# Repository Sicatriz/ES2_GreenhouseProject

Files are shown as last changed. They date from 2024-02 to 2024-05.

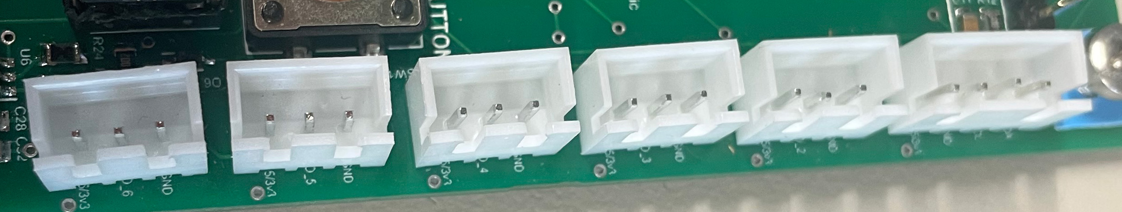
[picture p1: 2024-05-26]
doc/jstCon.jpg

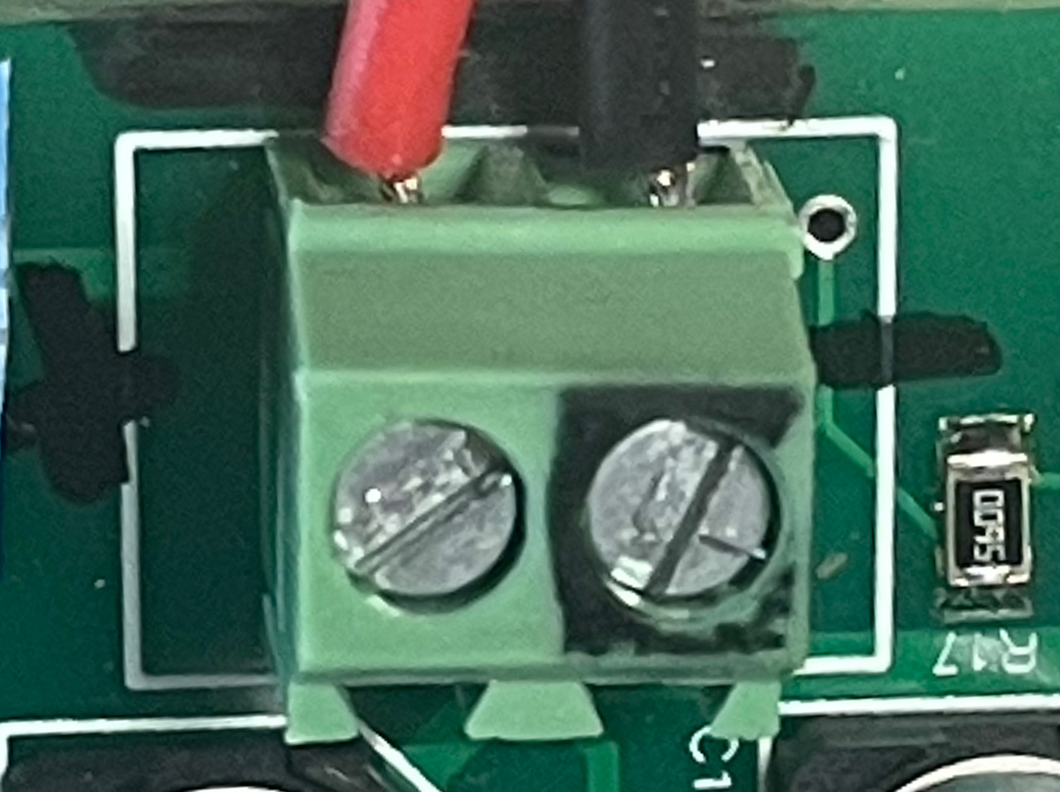
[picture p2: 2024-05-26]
doc/terminalBlock.jpg

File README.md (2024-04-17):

# **ES2 Greenhouse Project**

In dit onderzoek trachten wij een prototype te ontwerpen voor de automatisatie van een groeikas.  Op basis van de sensordata kunnen er dan acties aangestuurd worden zoals bewatering op basis van de grondvochtigheid, verluchting op basis van de temperatuur en/of schaduwvoorziening op basis van de lichtsterkte.

## **About the project**

## **Used sensors**

## **Schematic**

## **PCB design**

## **Software**

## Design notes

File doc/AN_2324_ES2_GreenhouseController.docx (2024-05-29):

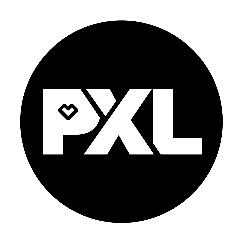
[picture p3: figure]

ELEKTRONICA-ICT

Elektronische systemen 2 2023-2024

GREENHOUSE CONTROLLER

Author | Miguel Nunez Xander Aerts

# Abstract

This paper introduces a novel approach for the development of a prototype controller tasked with sensor data acquisition tailored for greenhouse environments. The study focuses on the design, implementation, and evaluation of an integrated system facilitating real-time data collection and analysis to optimize growth conditions within greenhouses.

Content

# 1 Introduction

Greenhouse agriculture plays a crucial role in ensuring food security and sustainable food production amid an increasingly variable climate and environment. Precise monitoring and control of growth conditions within greenhouses are imperative for maximizing yield and minimizing resource consumption. In this context, this research focuses on developing a prototype controller capable of reading sensors to measure critical parameters influencing crop growth.

The proposed prototype is driven by the combination of an ATMega 328PU chip from an Arduino Uno and an ARM Cortex M4 processor from an Arduino 33 BLE. This combination of microcontrollers provides the computational power and connectivity necessary for real-time data collection and processing in a greenhouse environment.

The sensor values measured include air and soil humidity, temperature, electrical soil conductivity, and air pressure. These parameters are vital for understanding growth conditions and identifying potential stressors affecting plant growth.

The prototype design incorporates a modular architecture that offers flexibility for adjustments to various greenhouse configurations and crop types. By integrating electronics and sensor technologies, this research aims to deliver an accurate and reliable control system empowering growers to gain real-time insights and optimize their cultivation practices.

# 2 Hardware

## 2.1 PCB

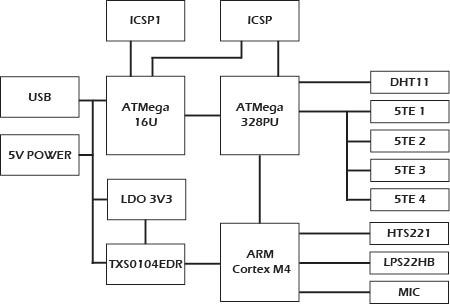
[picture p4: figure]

## 2.1.1 Block diagram and schematic

Figure 1: block diagram

The controller can be powered via micro USB or a 5V DC power jack. Programming of the chips can be done through the same micro USB port or via the ICSP1 and ICSP header.

The ATMega chip circuits are directly powered with 5V, while the ARM chip circuit is powered with 3.3V through the LDO and level shifter.

The ATMega16U serves as both a USB to serial converter and can be configured, via JP3, into different modes (Debugwire support, ISP programmer, or ISP header).

The ATMega328PU circuit processes the DHT11 and 5TE sensors, while the ARM circuit handles the built-in sensors from the Arduino 33 Sense BLE.

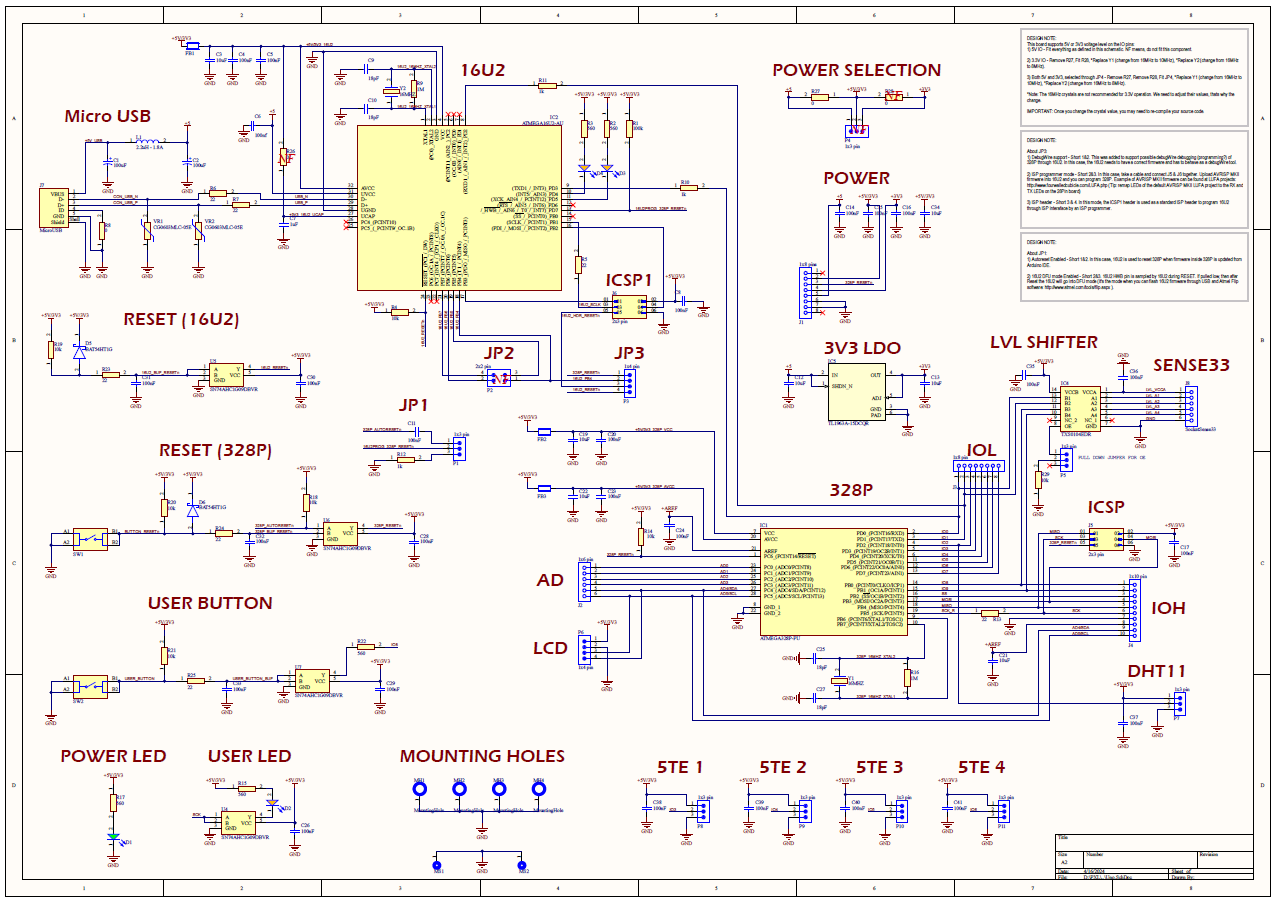
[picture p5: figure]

Figure 2: Schematic

## 2.1.2 PCB layout

The bottom plane comprises three distinct zones: ground, 5V, and 3V, as delineated in Figure 3 by respective blue, red, and green markings. This configuration facilitates easy access to the voltage channels for all components, while also partially mitigating electromagnetic interference (EMI) and electromagnetic susceptibility (EMS).

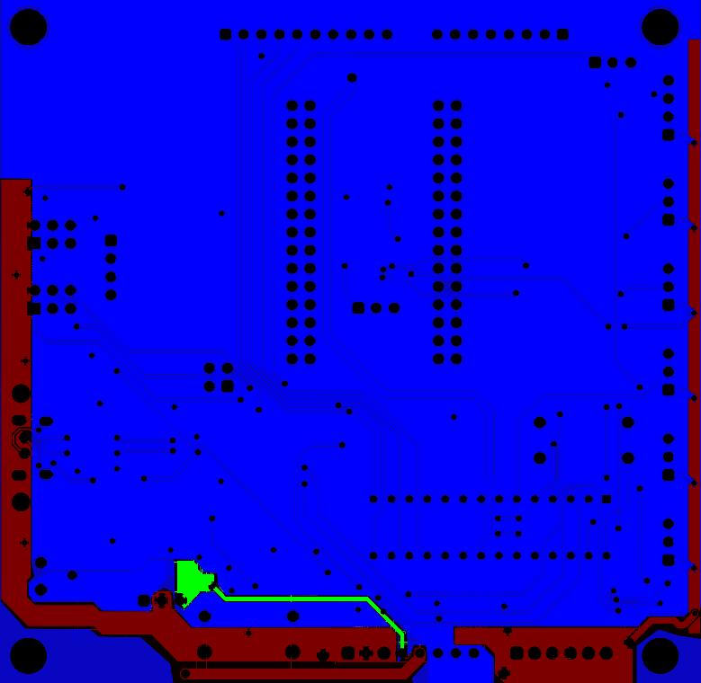
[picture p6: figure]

Figure 3: Bottom layer with ground, 5V and 3.3V polygons

The majority of signal traces are situated on the top layer. As depicted in Figure 4, the distribution is demarcated by a red colour for the Uno circuit, a green colour for the Sense BLE and level shifter circuit, and blue colour for the sensor connectors.

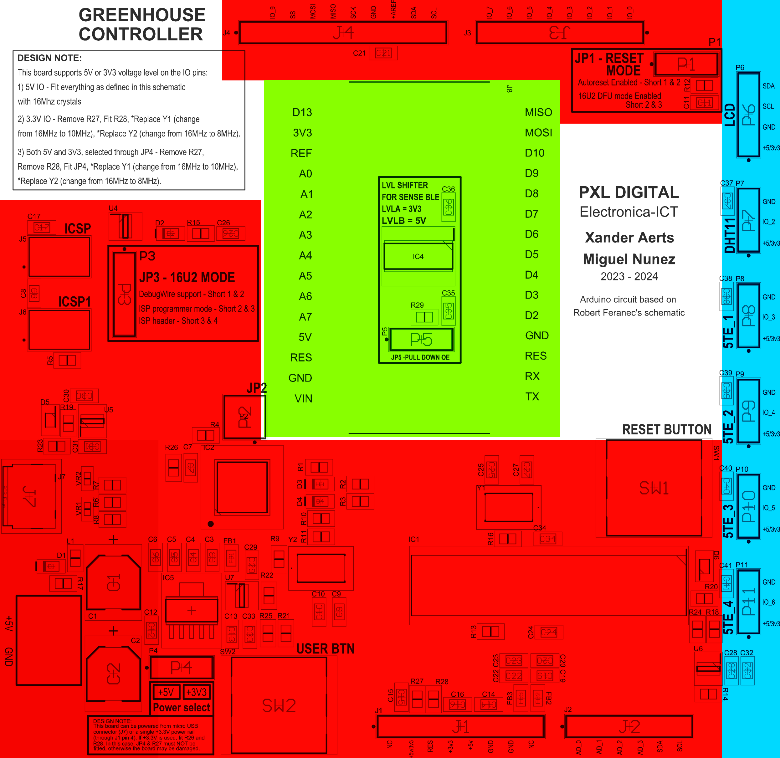
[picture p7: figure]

Figure 4: Top layer zones

## 2.1.3 Board connectors

## 2.1.3.1 Micro USB

The micro USB port serves the dual function of supplying power to the system and facilitating programming via the Arduino IDE. The USB connector was further mechanically reinforced via the addition of a metal bridge. Nevertheless, practical issues have been encountered with these connectors. Following exposure to the reflow oven, the data pins exhibited instances of short circuiting, impeding the successful uploading of sketches. After solving this short and despite recognition by the computer upon connection of the USB cable, sketch uploading functionality remains suboptimal.

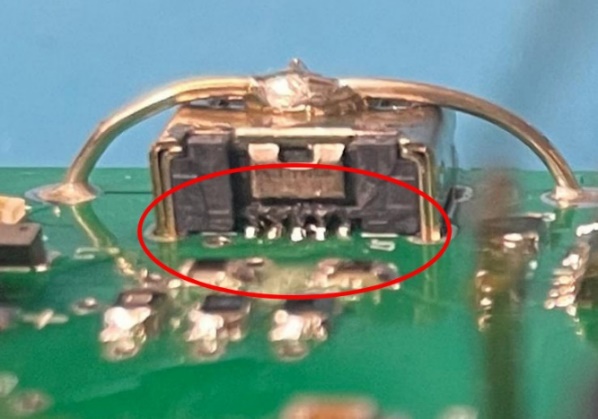
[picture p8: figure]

Figure 5: MicroUSB with shorted datapins

## 2.1.3.2 JST XH

JST type connectors are integrated on the PCB for connecting the sensor connectors and the LCD module, facilitating rapid assembly and disassembly.

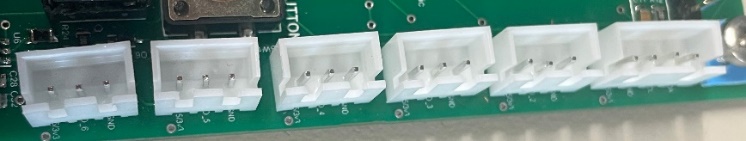
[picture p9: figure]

Figure 6: JST connectors for sensors and display

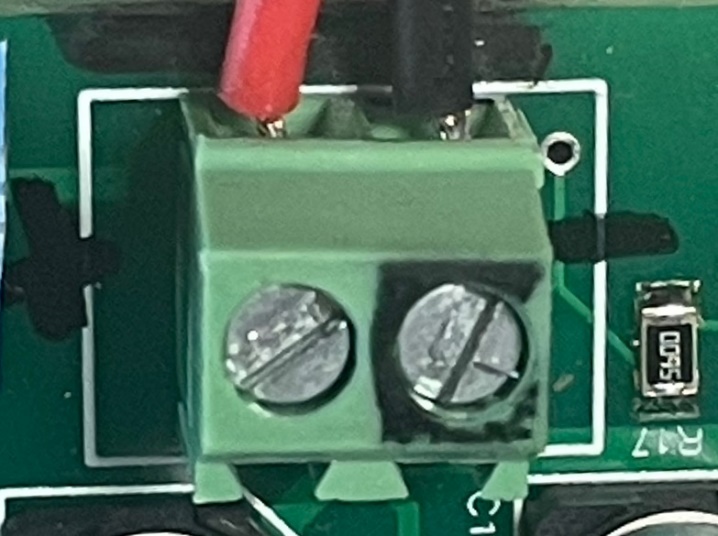
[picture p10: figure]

## 2.1.3.3 Terminal Block

Figure 7: Terminal block for power

A terminal block is incorporated to supply power to the controller independently of the USB connector. This terminal block is connected to a power jack on the enclosure, facilitating the seamless use of standard adapters.

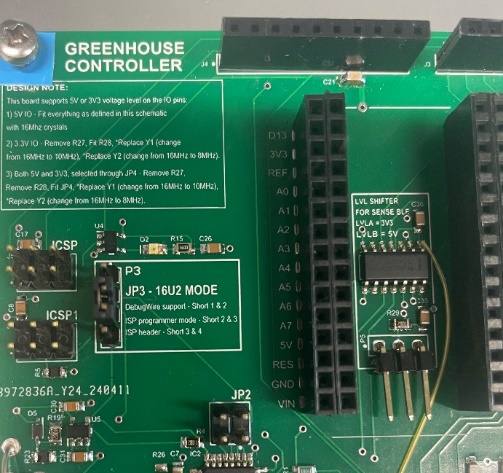
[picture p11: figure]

## 2.1.3.4 Headers

Figure 8: Pin headers and sockets

Several sockets, including J4, J3, J2, and J1, are provided to make the unused GPIOs accessible for expansions. Additionally, there are pin headers with specific functions: ICSP and ISCP1 for programming the ATMega ICs, JP3 for selecting the programming mode, JP1 for selecting the reset mode, JP2 for modifying the ATMega16u settings, P4 for power selection, and P5 for activating the pull-up of the level shifter. J8 is a custom-made footprint designed to duplicate the pins of the Arduino 33 Sense.

## 2.2 Sensoren

## 2.2.1 5TE

The 5TE 3-Prong Design sensor, developed by Decagon, is a versatile and cost-effective instrument used to measure volumetric water content (VWC), electrical conductivity (EC), and temperature in soils. Utilizing capacitance/frequency domain technology at a 70 MHz frequency, the 5TE sensor minimizes the effects of soil texture and salinity, thereby enhancing measurement accuracy across diverse soil types. The sensor's robust design includes a stainless steel electrode array for EC measurement and an onboard thermistor for temperature detection.

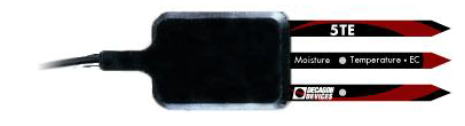
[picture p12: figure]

Figure 9: 5TE sensor

One of the key features of the 5TE sensor is its compatibility with the SDI-12 communication protocol, a widely adopted standard for interfacing environmental sensors with data loggers and acquisition systems. SDI-12 allows multiple sensors to share a common three-wire bus (power, ground, and data), facilitating efficient data collection from numerous sensors with unique addresses on a single bus. This protocol supports two-way communication, enabling the data logger to both send commands to and receive data from the sensor.

The SDI-12 implementation in the 5TE sensor supports standard commands for sensor identification, measurement initiation, and data retrieval. For instance, the INFO command (aI!) returns detailed sensor information, including the sensor's address, manufacturer, model, version, and serial number. The MEASUREMENT command (aM!) triggers the sensor to begin measurements, while the DATA command (aD0!) retrieves the measured values of VWC, EC, and temperature.

Decagon has optimized the 5TE sensor's SDI-12 circuit to support up to 62 sensors on a single bus, significantly exceeding the standard limit of 10 sensors. This enhancement is achieved through a low impedance variant of the standard SDI-12 circuit, although it necessitates careful bus management to handle potential faults and ensure reliable operation. The sensor’s digital communication capabilities, low power consumption, and robust encapsulation make it well-suited for long-term field deployments in diverse environmental conditions.

For detailed integration guidelines and to troubleshoot potential issues related to bus configuration, power supply, and grounding, users are encouraged to consult Decagon's comprehensive integrator guide. This document provides essential information for establishing reliable communication between the 5TE sensor and data acquisition systems, ensuring accurate and consistent environmental monitoring.

## 2.2.2 DHT11

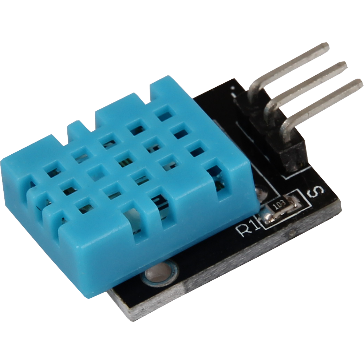
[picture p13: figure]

The SEN-KY015TF DHT11 sensor is a cost-effective and reliable device used to measure temperature and relative humidity. It operates with a temperature range of 0°C to 50°C and a humidity range of 20% to 90% RH, providing accuracies of ±2°C and ±5% RH, respectively. The sensor communicates via a single-wire digital protocol, making it easy to integrate into various systems. Common applications include environmental monitoring, home automation, agricultural management, and industrial processes where basic environmental sensing is required.

Figure 10: DHT11 sensor

Integrating the DHT11, expands its utility in complex and remote environmental monitoring setups. This integration facilitates reliable data acquisition and enhances the sensor’s applicability in diverse and demanding environments.

## 2.2.3 Sense 33 BLE

The Arduino Nano 33 BLE Sense is an excellent platform for embedded machine learning, integrating numerous sensors alongside its nRF52840 microcontroller running on Arm® Mbed™ OS. This board is equipped with a powerful 2.4 GHz Bluetooth® 5 Low Energy module, allowing for seamless wireless communication using the ArduinoBLE library.

For motion detection, the LSM9DS1 inertial measurement unit combines a 3D accelerometer, gyroscope, and magnetometer, enabling precise orientation, motion, and vibration sensing. Audio applications benefit from the MP34DT05 omnidirectional digital microphone, which captures sound for real-time analysis, supported by the PDM library. Proximity and gesture detection are facilitated by the APDS9960 sensor, which can be programmed to recognize hand gestures and control the built-in RGB LED. The LPS22HB barometric pressure sensor provides accurate pressure measurements and can calculate altitude, while the HTS221 sensor measures both temperature and humidity with high accuracy, making it ideal for environmental monitoring.

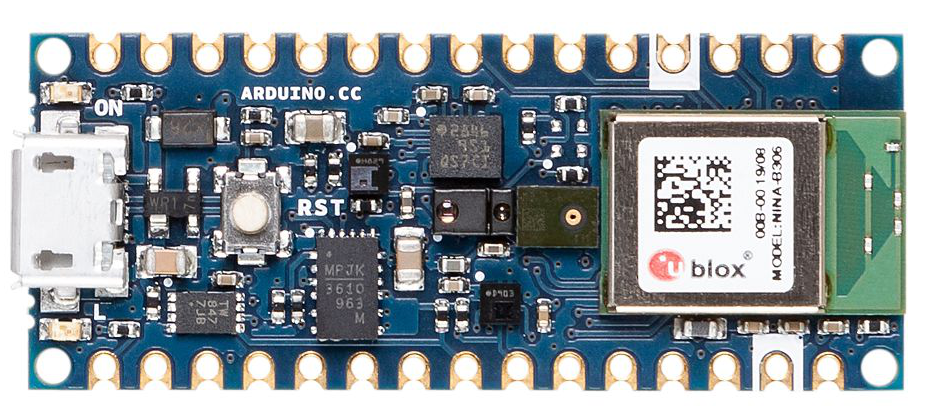
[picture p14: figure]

Figure 11: Arduino Nano 33 sense BLE

## 2.3 LCD display

For visualizing data in this project, we utilized the HD44780 16x2 LCD display, known for its simplicity and effectiveness in displaying alphanumeric characters. This module, measuring 80 mm x 36 mm x 12.5 mm, features a 16-character by 2-line resolution, making it ideal for clear and concise data presentation. It supports both 3.3V and 5V operating voltages and offers a wide operating temperature range from -10°C to +60°C, ensuring reliable performance in various environments.

The HD44780 display includes a white LED backlight and operates in both 8-bit and 4-bit parallel modes, offering flexibility in microcontroller interfacing. Key pins like RS, RW, and E facilitate easy control over data and command registers, while the VO pin allows for contrast adjustment. The module's robust design and straightforward connection to microcontrollers like Arduino make it an excellent choice for embedding real-time data visualization into projects.

## 2.4 Behuizing

In this project, an enclosure was designed and 3D-printed in PLA (polylactic acid) to protect and house the electronic components. The choice of PLA offers several advantages: it is biodegradable, easy to print, and has a low shrinkage factor, ensuring accurate results. The enclosure is designed with ventilation openings in an organic shape representing air bubbles, creating an aesthetically pleasing and functional design that allows efficient air circulation.

3D printing offers significant advantages in the prototyping phase of a project. It enables designers to quickly iterate and test physical models, saving time and costs compared to traditional manufacturing methods. Additionally, complex geometries and customized designs can be easily realized without extra production costs. This accelerates the development cycle and allows for rapid adjustments based on feedback and testing, ultimately leading to a superior final product.

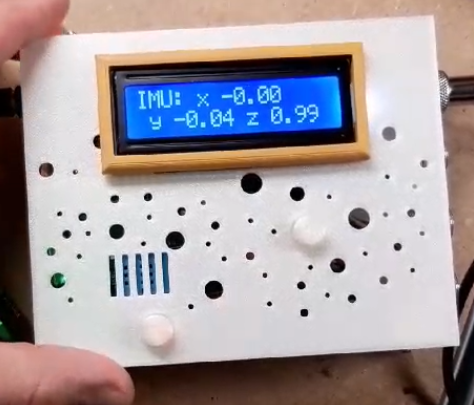
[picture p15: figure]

Figure 12: Enclosure front panel

# 3 Software

## 3.1 Bootloader

The installation of the bootloader software on the ATMega16U2 chip was performed using AVRDude. However, issues persisted in programming the ATMega328PU chip via USB following this procedure. Despite successful recognition of the USB and chips and the seamless power supply to the system, programming difficulties remained. Even when we tried using the new ATMega328PU chip with a working bootloader from Arduino themselves we were unable to program it with the Arduino IDE. Due to this reason we can confidently say that part of the problem lies with that IC. And given the time constraints, it was decided to use an off the shelf ATMega328PU chip using an off the shelf Arduino UNO board and subsequently place the programmed chip into the socket of our system. Besides AVRDude on its own we also tried to use the build in “burn bootloader” functionality of the Arduino IDE which involved another Arduino board and used AVRDude at its core. This would have burned the bootloader on the ATMega328PU chip but this also was in vein partially due to a limited time.

## 3.2 Application software

The application software is split into two parts, one being the Arduino Nano 33 BLE Sense that collects the onboard sensor data while the other is the integrated Arduino uno that will collect the external sensor data. In the following blocks we will further explain the code and the different problems that we encountered.

## 3.2.1 Arduino Nano 33 BLE Sense (Sender)

The Nano Contains multiple onboard sensors where we were given the task to display those values on a display together with the external temperature/humidity sensor and the ground-sensors. The Nano will firstly gather all the sensor data and store them in variables. After that it will combine those values in a message that will be send to the Arduino Uno over UART. An example of such a message would be the following:

temp>24.5>hum>52.47>pres>102.5>imu>-0.2, 0.05, -0.42>col>12, 13, 8>*>

The ‘>’ sign is used to separate the different sensor values and most importantly, to make parsing that data on the uno’s side much easier. When finished the message will be transmitted to the uno over the Serial1 port, which is connected to the external pins and wait for 3 seconds before reading the data again and redoing the cycle all over again.

## 3.2.2 Integrated Arduino Uno (Receiver)

The Uno will on its turn connect to the ground-sensor and wait for 3 seconds during startup to allow the sensors to start. We found that the sensors themselves are realy slow in for example sending back data when requested so allowing the sensors to connect properly and start will give us a more reliable application. After the startup the main loop will continuously go through the following 3 main blocks in order:

## 3.2.2.1 Select button

In the first block, it will see if the userbutton was pressed and if so it will set the screenstate variable plus one. This value will later be used to tell the board what sensor data to show on the lcd screen. The main problem when implementing this functionality was the bounce effect of the button, basically the Arduino whould read more the one button press due to the mechanical functionality of it. This was resolved by implementing a software Schmitt-trigger that would not only look at the current state of the button but also at the previous state to ensure that there realy is a new buttonpress.

## 3.2.2.2 Receiver

After that it will check if there are UART messages available in the internal buffer if so, it will keep on reading them and adding them to a string until it encounters the ‘*’ symbol meaning that the message is complete. After which it will set the parse flag to true, which gives the signal to the following parse block to start processing the message.

## 3.2.2.3 Parser

When the parse flag is set to true, the parser will begin with reading out the ground-sensors data and store them in the according variables. Immediately after that it will start processing the message by cutting it into pieces at the previously described ‘>’ symbol. Afterwards it will use this data together with the agreed-upon format to parse the sensor data out of the message and store them also in the proper locations. When all these steps are done it will enter the “switch case” where, according to the screenstate variable (that was set by the user button), the according sensordata will be shown on the screen.

A half a second delay will end the loop and restart the process once again.

## 3.2.3 Why UART

The reason for UART was because of its simplicity and functionality. When looking at all the options: I²C, SPI and UART we decided to utilize UART because it was meant to transmit messages in the form of characters in contrary of I²C which would need a more sophisticated format to function. With UART we were able to create a string message from which we new that we would be able to parse that on the uno’s side very easily while it would require more research to do that with I²C. So the main reason that we didn’t choose for SPI and I²C was due to more complexity and a lack of earlier experience with SPI.

## 3.2.4 Encountered problems

When working with the 2x16 lcd display we tried multiple library’s in the hopes that it would work on the nano but after multiple attempts we were unsuccessful to have it working even with a level-shifter in between to allow for 5v logic/power on the lcd’s side. The reason for this was the fact that all the librarys weren’t written for the arm architecture but for the atmel architecture. Because of this we decided to utilize an Arduino Uno (that was later integrated on the pcb) to drive the display. Later on we also used that microcontroller to read the external ground-sensors and the external temperature/humidity sensor. Due to insufficient time we haven’t been able to try and connect the ground-sensors to the Nano board and decided to leave it that way.

# 4 Result

The final result is a controller capable of reading sensor data from various sensors and displaying it on an LCD screen. Three hardware issues were identified:

The provision of a 3.3V power line between the LDO and the level shifter was missing. This was resolved by connecting the components with a rework cable.

The resistor intended to pull the OE pin of the level shifter to ground needed to be pulled high to the 5V line. We addressed this by connecting a THT resistor to an accessible 5V pin via the header.

Powering the Arduino 33 BLE through the VIN pin did not provide sufficient voltage to make that part of the system operational. We had to create internal connections from the MicroUSB of the 33 BLE to the 5V terminal block of the PCB.

In a subsequent revision of this board, these issues can be easily corrected in the design. The logical next step is to establish communication between this system and an external database or other devices via Bluetooth, enabling data logging. Based on this data, analyses can be performed, and it may also be possible to control infrastructure elements such as activating sprinklers, opening or closing windows, and adjusting curtains.

# 5 Discussion

The completion of this project marks a significant learning experience, highlighting both the challenges and the successes encountered throughout its development. Despite facing hardware issues during the implementation phase, the process provided invaluable insights into troubleshooting and problem-solving within an electronics project context. Moreover, the successful integration of various sensors and the LCD display demonstrates the feasibility of the proposed controller concept.

This project lays a solid foundation for further research and development in the field of greenhouse control systems. By addressing the identified hardware issues and refining the design, future iterations of the controller can be optimized for enhanced performance and reliability. Additionally, the potential for integrating communication capabilities, such as Bluetooth connectivity, opens up avenues for data logging and remote monitoring, thus increasing the system's versatility and utility.

Furthermore, the broader implications of this project extend beyond its immediate scope, suggesting its potential as a building block for a comprehensive greenhouse control solution. As part of a larger system, the controller developed in this project could serve as a crucial component in automating and optimizing greenhouse operations. By leveraging sensor data to regulate environmental conditions such as temperature, humidity, and lighting, the system could contribute to improved crop yield and resource efficiency.

# 6 Conclusion

Looking forward, the success of this project opens doors to further research and development, with opportunities for refining the controller's design and enhancing its functionality. By addressing hardware limitations and exploring avenues for communication improvements, we can pave the way for a more robust and reliable greenhouse management solution.

Moreover, the broader implications of this project are significant. It lays the groundwork for future advancements in agricultural technology, with the potential to revolutionize farming practices and contribute to global food security. As we continue to push the boundaries of what is possible, this project serves as a testament to the power of innovation and collaboration in addressing the challenges of tomorrow.

PXL 2023-2024 || Elektronische systemen 2 || Greenhouse Controller 2 / 3

https://www.pxl.be/elektronica-ICT 1 / 2

ELEKTRONICA SYSTEMEN 2 23-24

DIGITALE COMMUNICATIE 23-24

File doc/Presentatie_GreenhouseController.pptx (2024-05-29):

## Elektronische systemen II : Greenhouse controller

Xander aerts & miguel nunez

## “Groeioptimalisatie en duurzaam beheer van grondstoffen voor plant en planeet.”

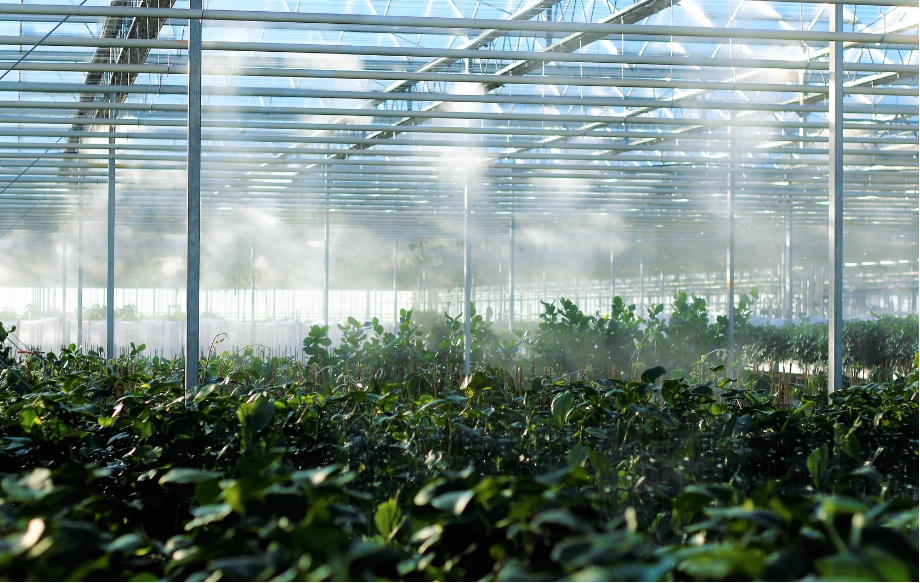
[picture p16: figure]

## Het proces

Analyseren ontwerpfouten en oplossen voor een volgende revisie

Research

Ontwerp

Debugging

Onderzoek van de sensoren en de communicatie protocollen.
Compatibiliteits met de processoren.

Samenvoegen van ATMega en ARM technologie in één product.

## Research

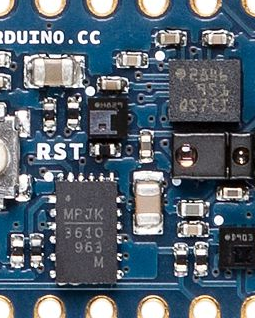
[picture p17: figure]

Arduino 33 Sense BLE
- MC hardware & sensoren: nRF52840 ARM CPU, APD9960 (licht), LPS22HB (druk), HTS221 (temperatuur en vochtigheid), LSM9DS (IMU), MP34DT05 (geluid)
Decagon 5TE sensor
- Grond sensor: Volumetrische water meting, grond temperatuur, grond conductiviteit
Joy-IT KY-015 DHT11
- Omgevingssensor: Lucht temperatuur en –vochtigheid.

## Ontwerp

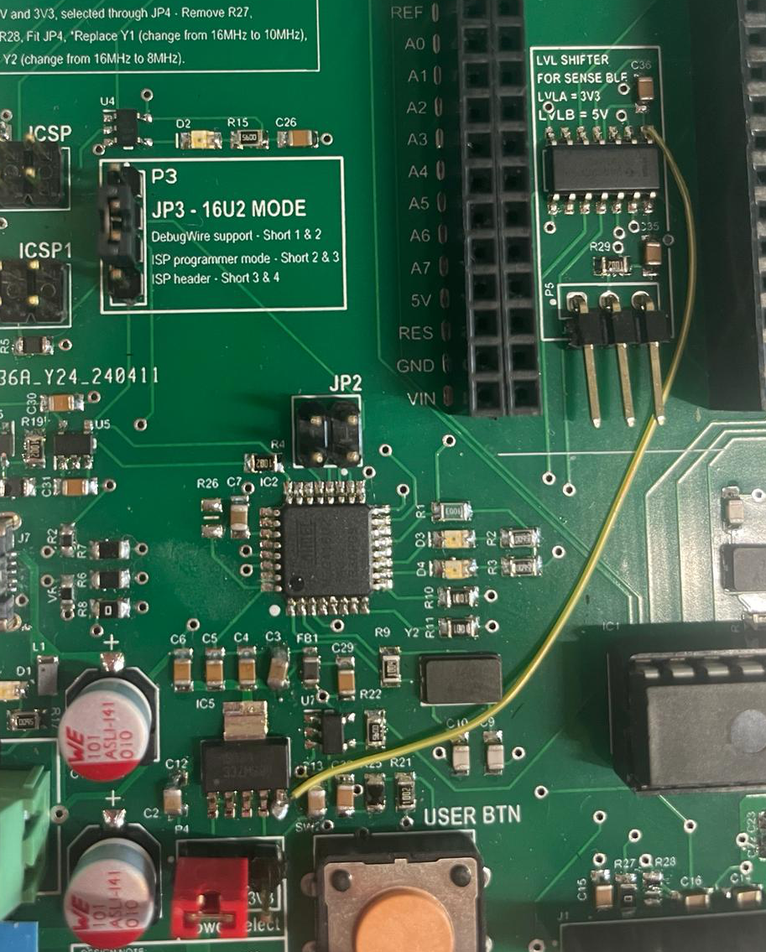
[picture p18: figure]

2 Arduino architecturen
- Aruino 33 sense BLE: leest de geïntegreerde sensoren uit
- Arduino UNO: leest de externe sensoren uit en stuurt de LCD aan
Alles geïntegreerd op één PCB die zowel een 5V circuit als een 3,3V circuit voorziet voor beide architecturen d.m.v. een level shifter, type TXS0104E

## Debugging

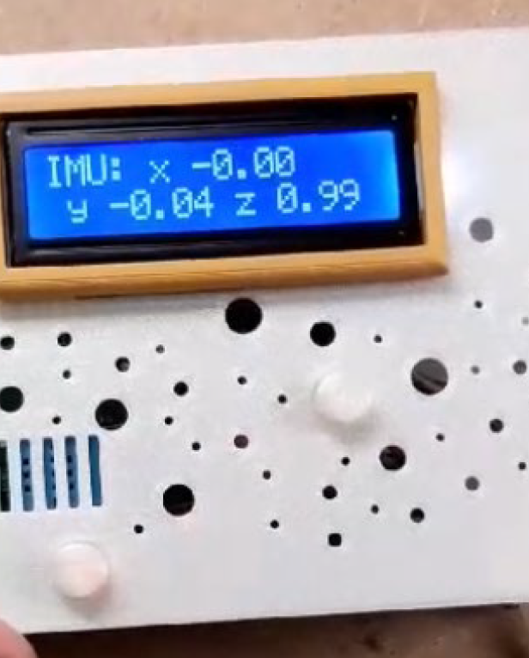
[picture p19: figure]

3 ontwerpfouten
- 3,3V trace naar levelshifter
- OE pin naar ground i.p.v. naar 5V
- VIN voeding ontoereikend → voeding via USB
Deze fouten zijn eenvoudig te corrigeren in een volgende revisie van de print.

## Software

De ATMega16U2 en ATMega328PU geflasht met AVRDude
Micro USB van UNO circuit werkt voor voeding maar geeft nog problemen om te programmeren

Firmware

Programma

De Sense BLE werkt als zender en de UNO als ontvanger via UART.
Voorbeeld:
temp>24.5>hum>52.47>pres>102.5>imu>-0.2, 0.05, -0.42>col>12, 13, 8>*>

## DEMO


## Bedankt voor uw aandacht!

Vragen?

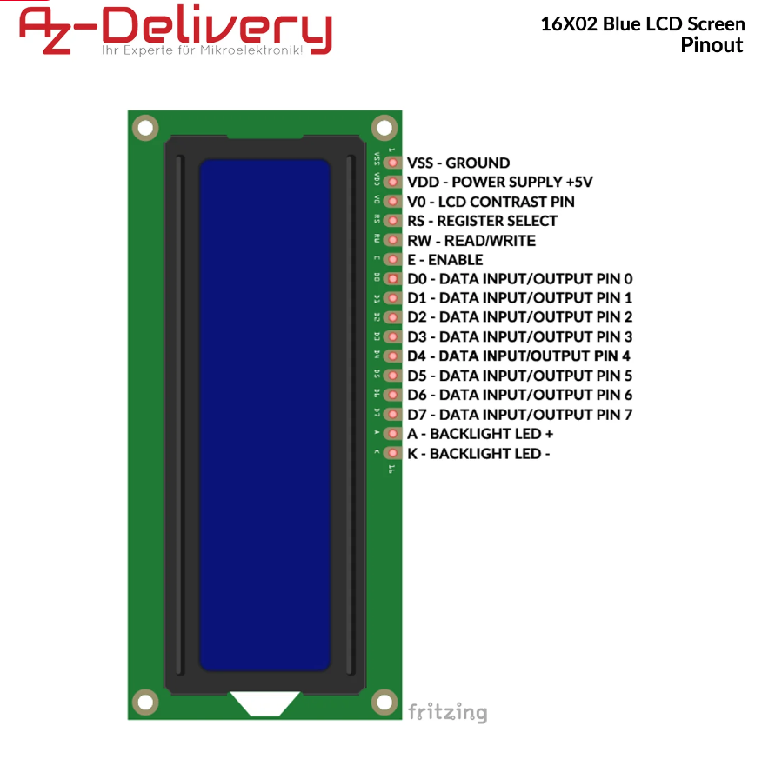
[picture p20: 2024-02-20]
Datasheets/HD44780_1602_pinout.PNG

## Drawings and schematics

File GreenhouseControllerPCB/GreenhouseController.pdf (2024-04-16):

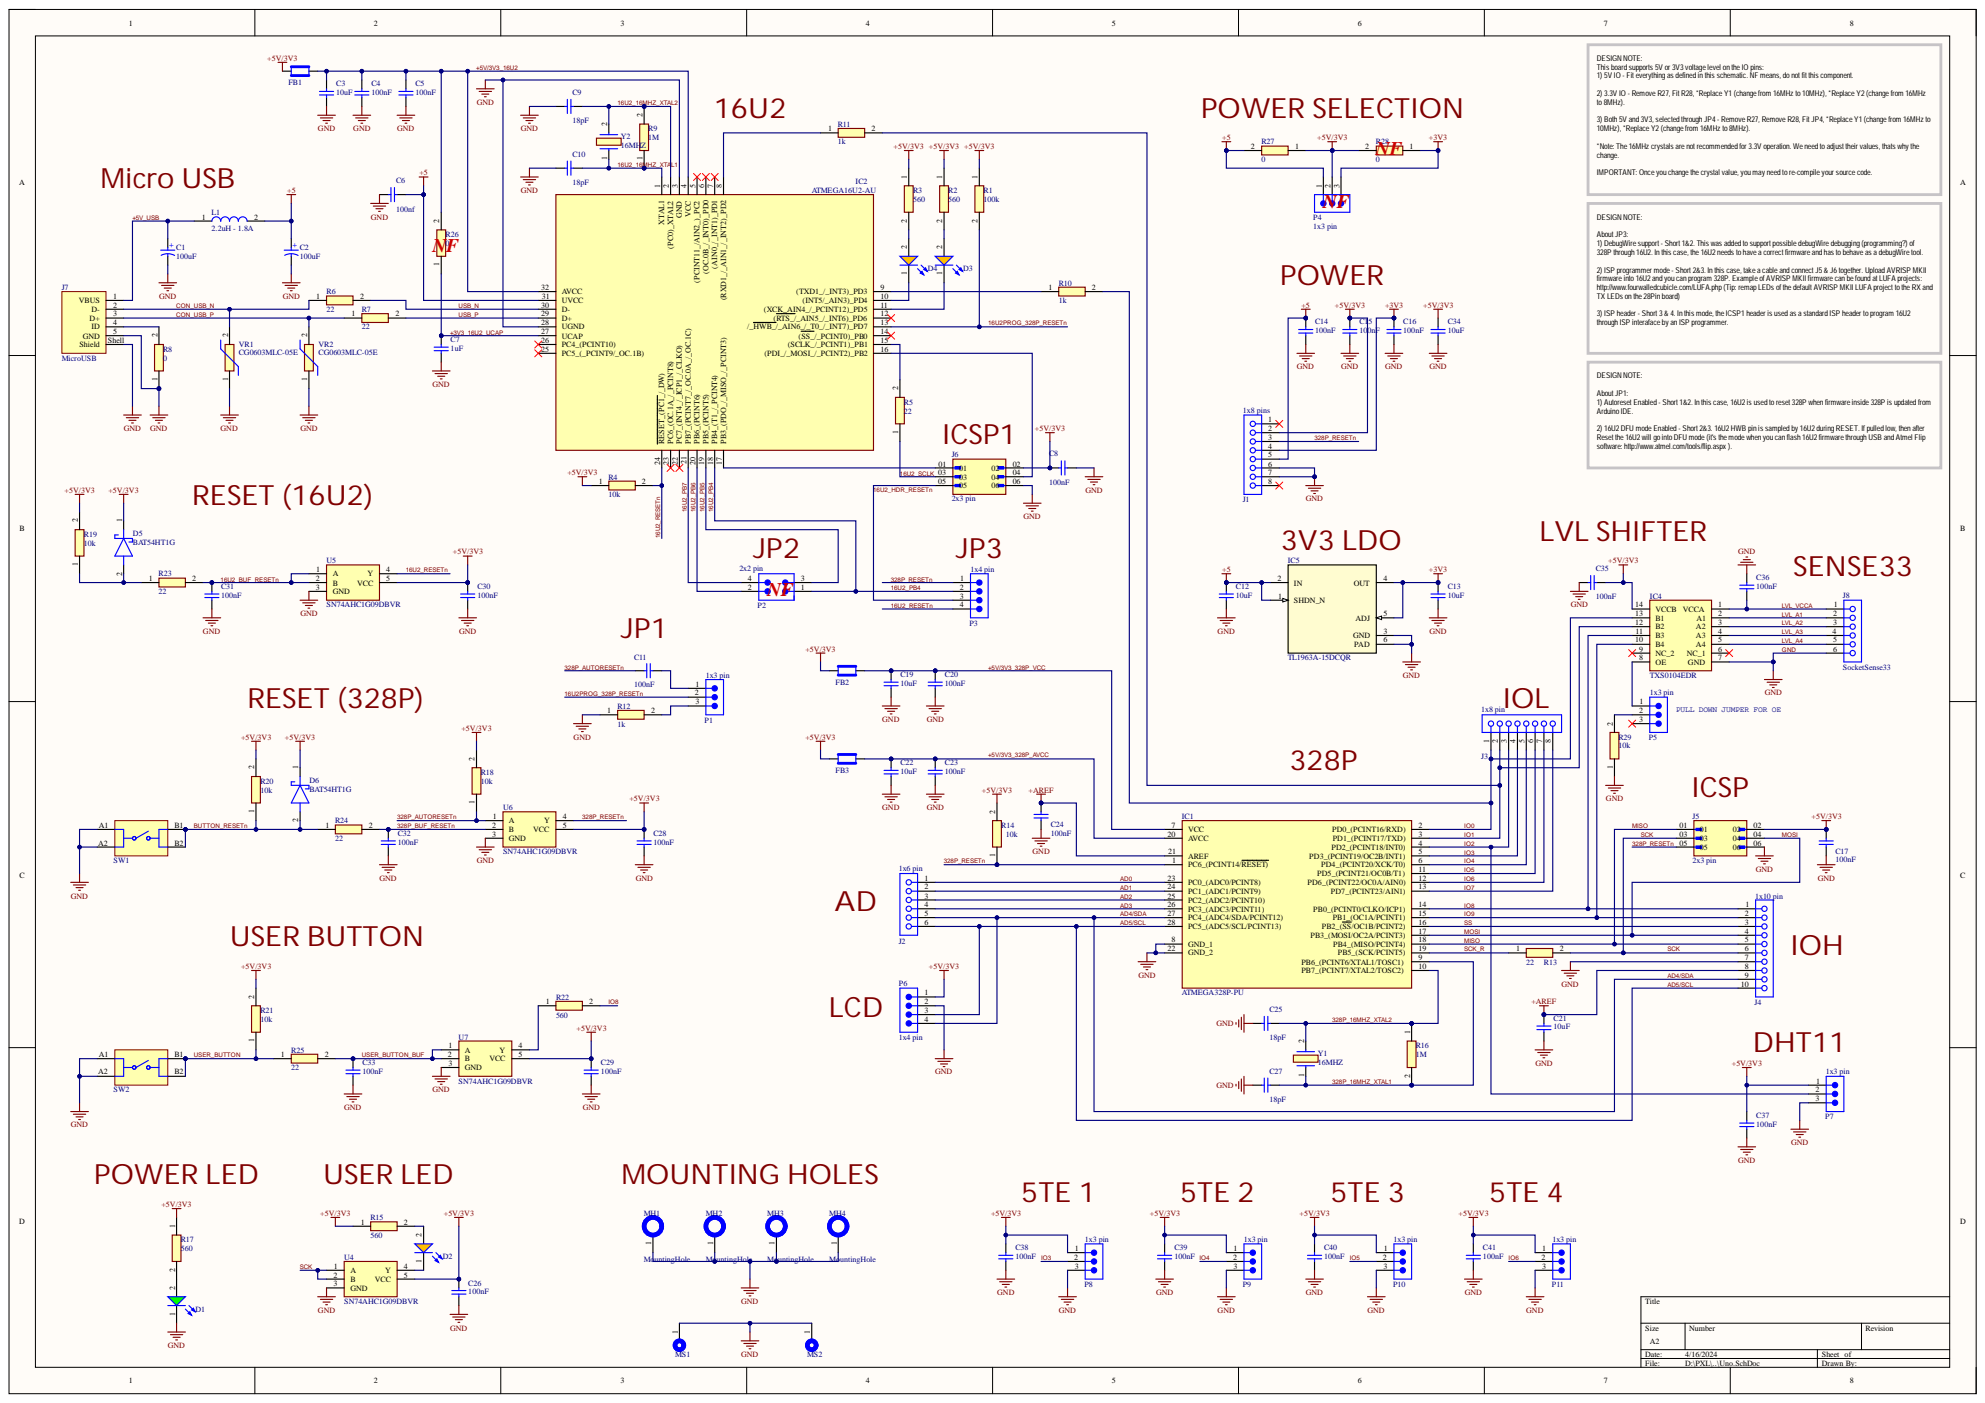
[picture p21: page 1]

DESIGNNOTE:
This board supports 5V or 3V3 voltage level on the IO pins:
1) 5V IO - Fit everything as defined in this schematic. NF means, do not fit this component.

2) 3.3V IO - Remove R27, Fit R28, *Replace Y1 (change from 16MHz to 10MHz), *Replace Y2 (change from 16MHz
to 8MHz).

3) Both 5V and 3V3, selected through JP4 - Remove R27, Remove R28, Fit JP4, *Replace Y1 (change from 16MHz to
10MHz), *Replace Y2 (change from 16MHz to 8MHz).

*Note: The 16MHz crystals are not recommended for 3.3V operation. We need to adjust their values, thats why the
change.

IMPORTANT: Once you change the crystal value, you may need to re-compile your source code.

GND | 18pF

About JP3:
1) DebugWire support - Short 1&2. This was added to support possible debugWire debugging (programming?) of
328P through 16U2. In this case, the 16U2 needs to have a correct firmware and has to behave as a debugWire tool.

2) ISP programmer mode - Short 2&3. In this case, take a cable and connect J5 & J6 together. Upload AVRISP MKII
firmware into 16U2 and you can program 328P. Example of AVRISP MKII firmware can be found at LUFA projects:
http://www.fourwalledcubicle.com/LUFA.php (Tip: remap LEDs of the default AVRISP MKII LUFA project to the RX and
TX LEDs on the 28Pin board)

3) ISP header - Short 3 & 4. In this mode, the ICSP1 header is used as a standard ISP header to program 16U2
through ISP interaface by an ISP programmer.

About JP1:
1) Autoreset Enabled - Short 1&2. In this case, 16U2 is used to reset 328P when firmware inside 328P is updated from
Arduino IDE.

3 4 | | 328P_RESETn
5 | 3V3 LDO

2) 16U2 DFU mode Enabled - Short 2&3. 16U2 HWB pin is sampled by 16U2 during RESET. If pulled low, then after
Reset the 16U2 will go into DFU mode (it's the mode when you can flash 16U2 firmware through USB and Atmel Flip
software: http://www.atmel.com/tools/flip.aspx ).

GND | 2 3

PULL DOWN JUMPER FOR OE

6 | | | AD5/SCL | PC5_(ADC5/SCL/PCINT13) 28 PB2_(SS/OC1B/PCINT2) | 16 SS | | | 3

PB3_(MOSI/OC2A/PCINT3) GND_1 8 PB4_(MISO/PCINT4) PB5_(SCK/PCINT5) | 17 MOSI | | 4

18 MISO | | | | 5

GND_2 22 | 19 SCK_R | 1 2 | SCK | | 6

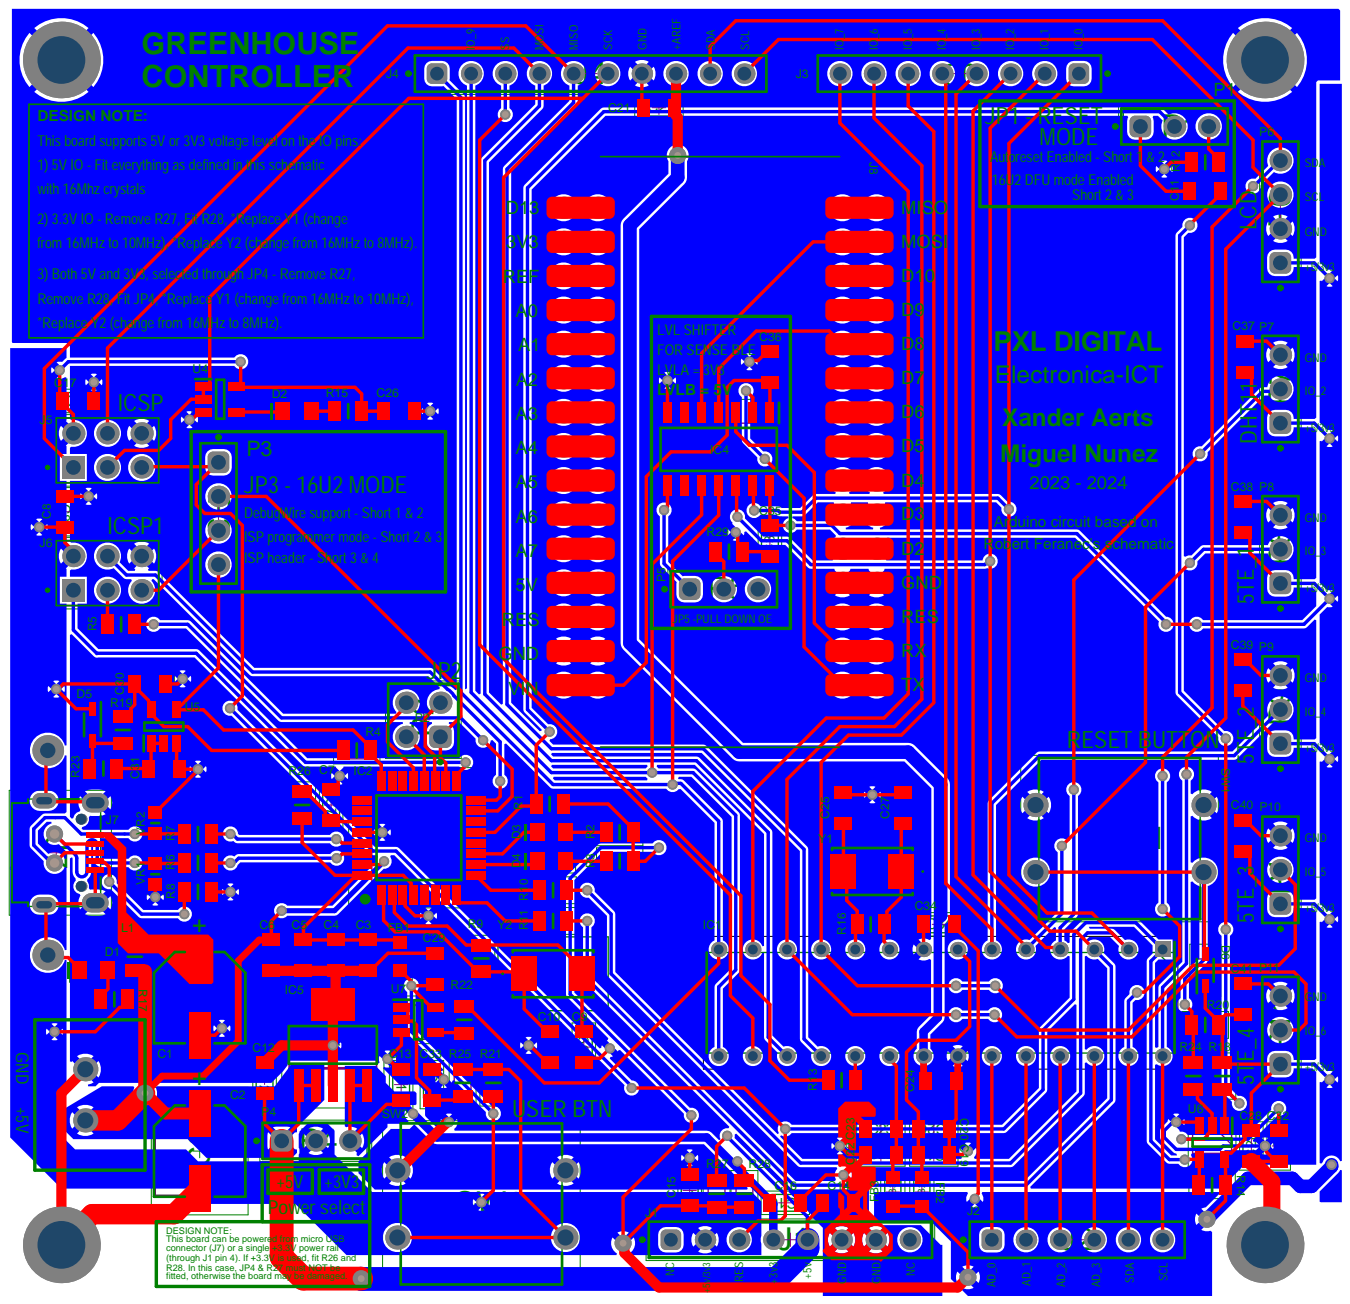
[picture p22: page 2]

DESIGN NOTE: This board supports 5V or 3V3 voltage level on the IO pins: 1) 5V IO - Fit everything as defined in this schematic with 16Mhz crystals 2) 3.3V IO - Remove R27, Fit R28, *Replace Y1 (change from 16MHz to 10MHz), *Replace Y2 (change from 16MHz to 8MHz). 3) Both 5V and 3V3, selected through JP4 - Remove R27, Remove R28, Fit JP4, *Replace Y1 (change from 16MHz to 10MHz), *Replace Y2 (change from 16MHz to 8MHz). | | C21

DebugWire support - Short 1 & 2
ISP programmer mode - Short 2 & 3
ISP header - Short 3 & 4

Arduino circuit based on
Robert Feranec's schematic

DESIGN NOTE:
This board can be powered from micro USB
connector (J7) or a single +3.3V power rail
(through J1 pin 4). If +3.3V is used, fit R26 and
R28. In this case, JP4 & R27 must NOT be fitted, otherwise the board may be damaged.

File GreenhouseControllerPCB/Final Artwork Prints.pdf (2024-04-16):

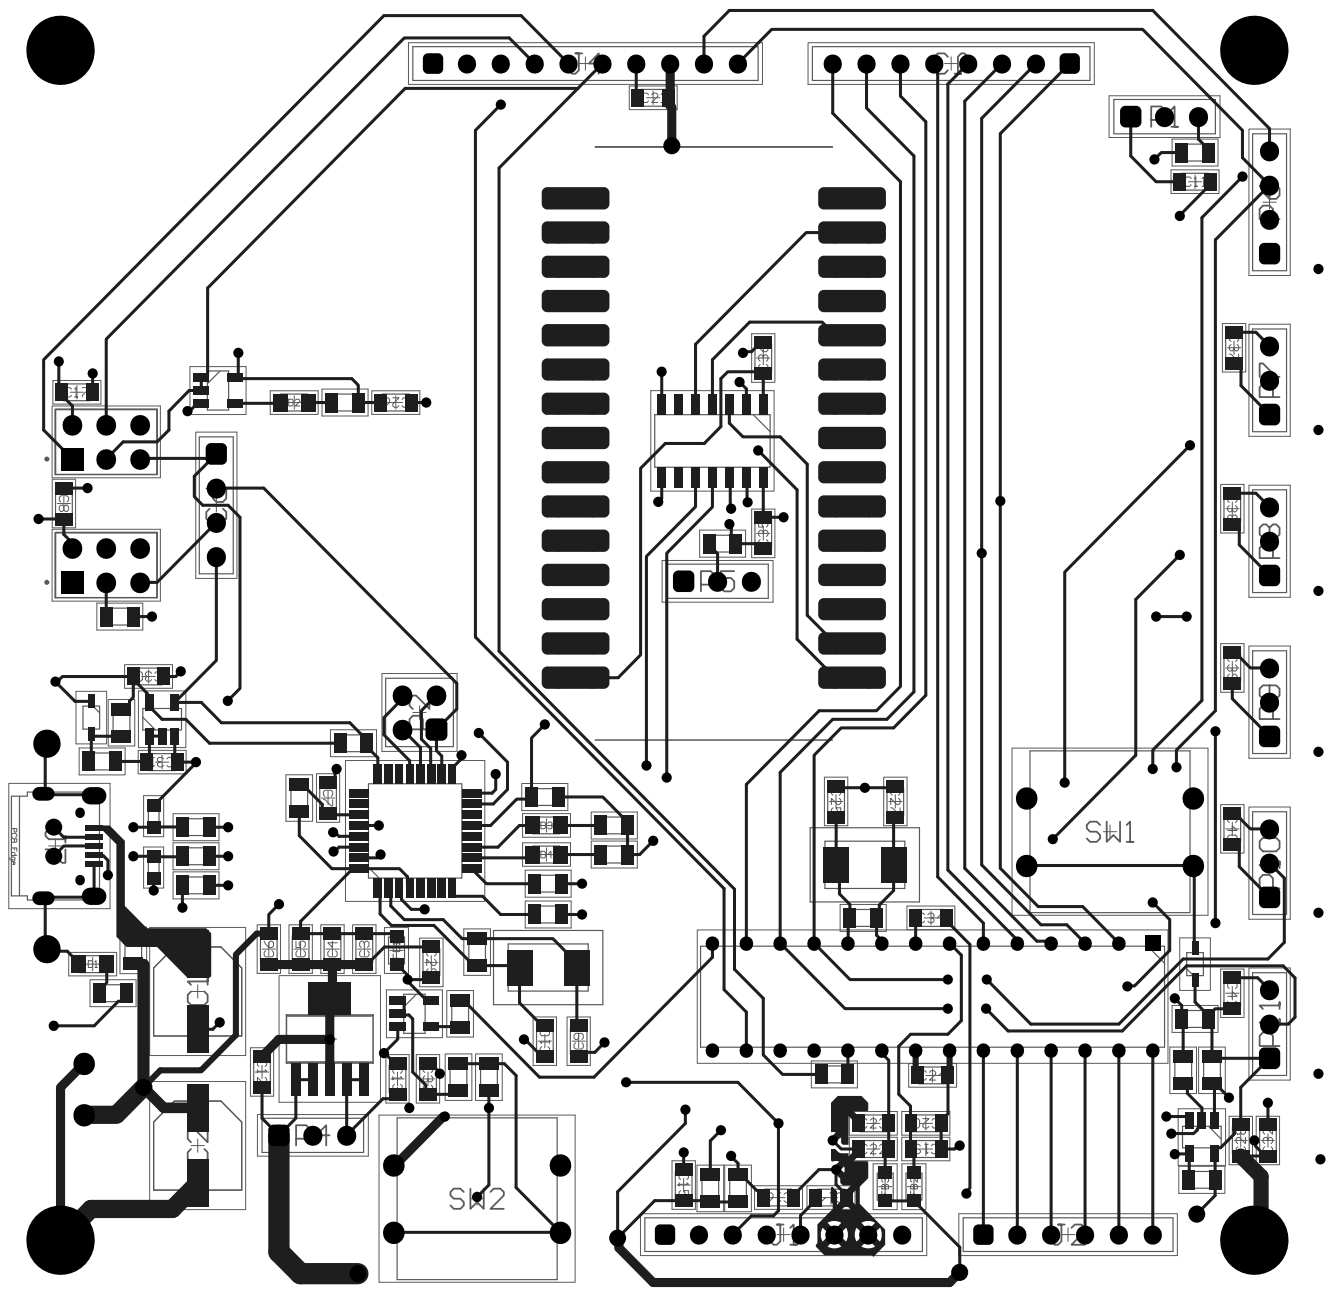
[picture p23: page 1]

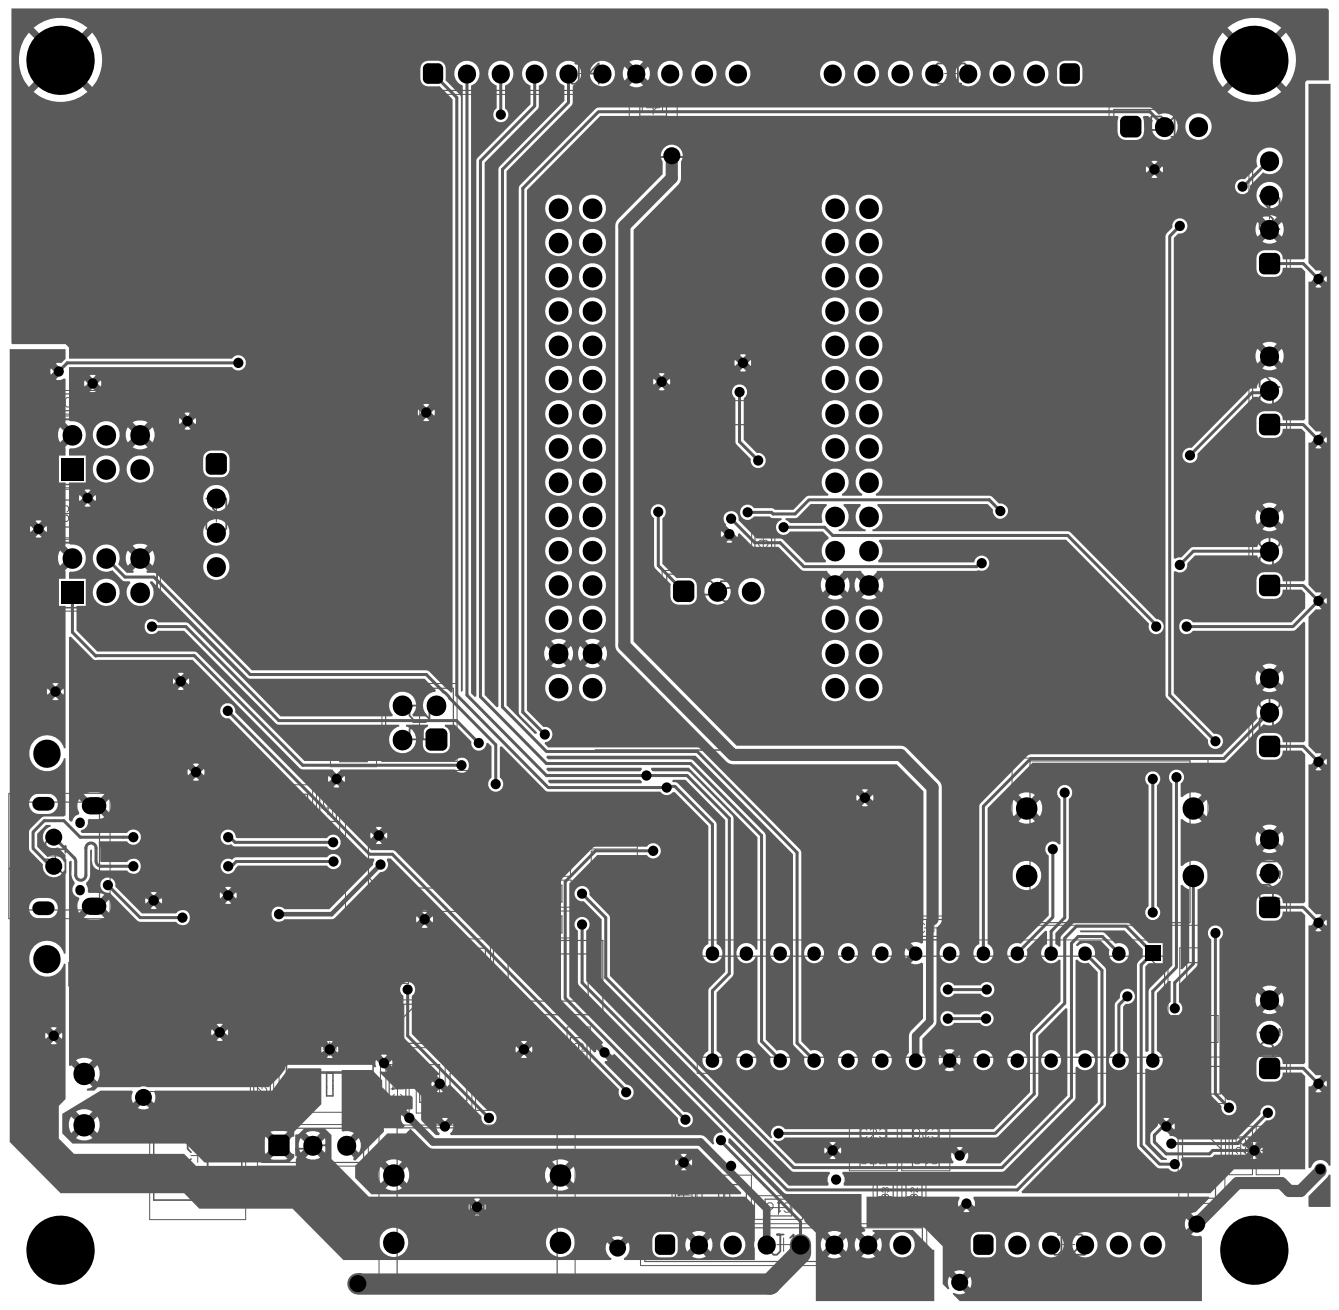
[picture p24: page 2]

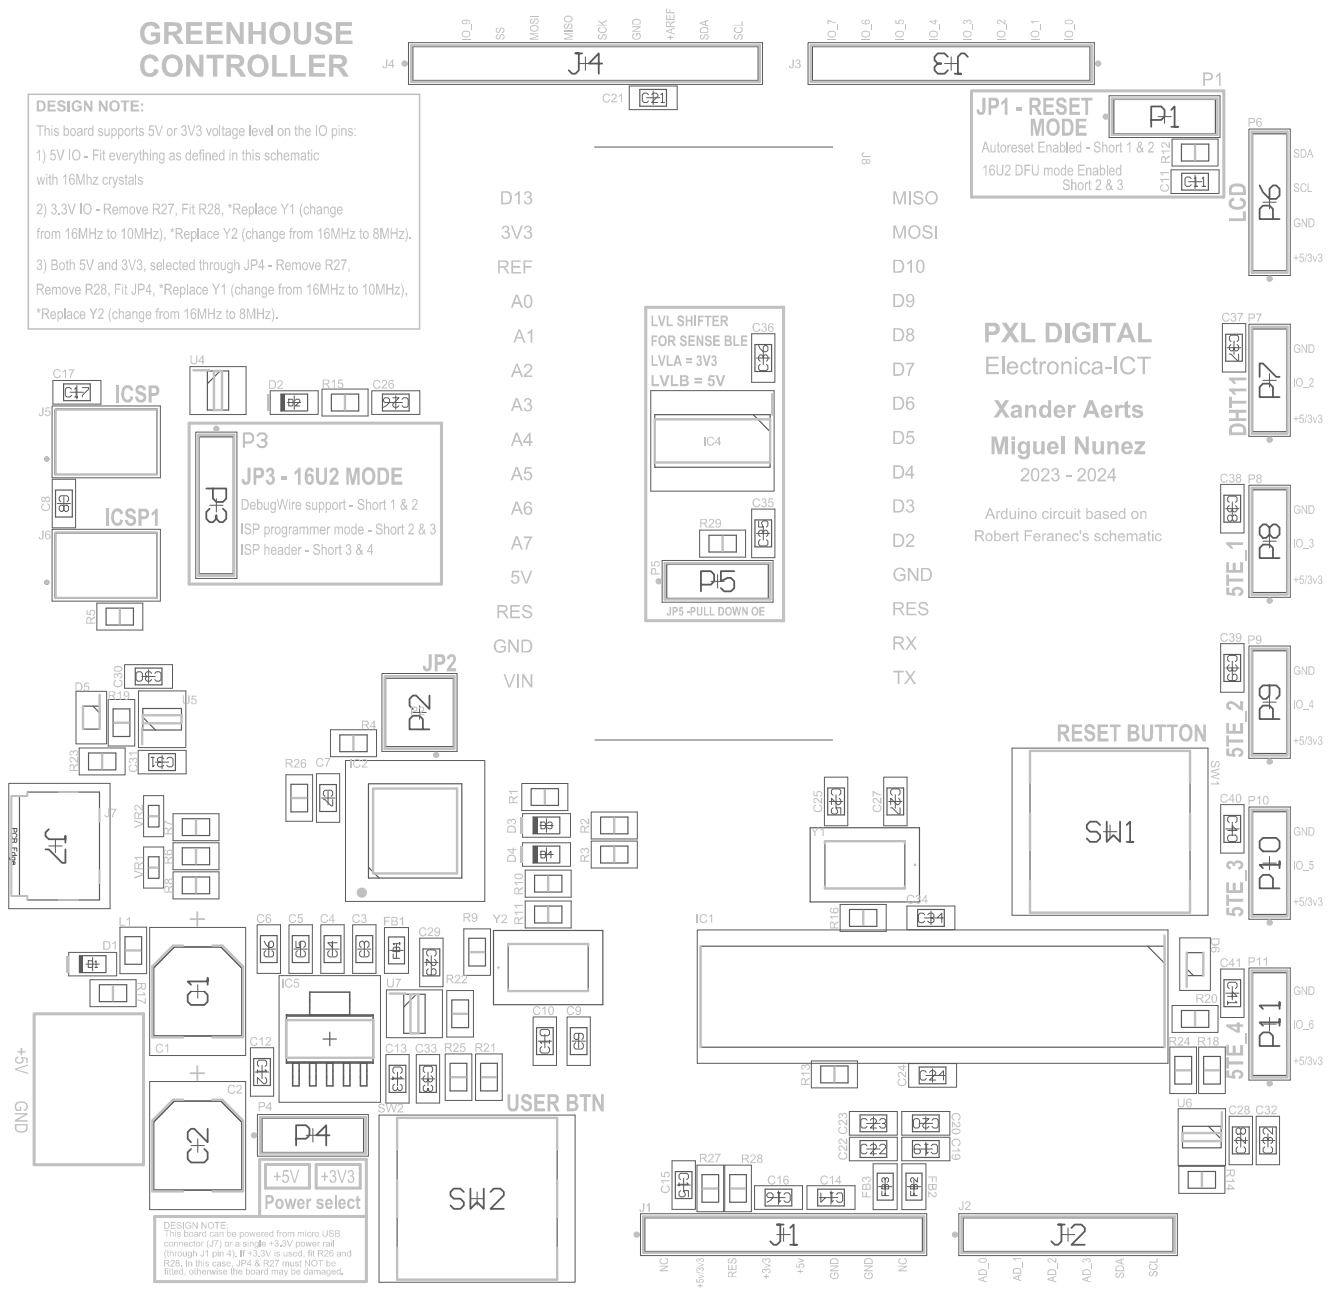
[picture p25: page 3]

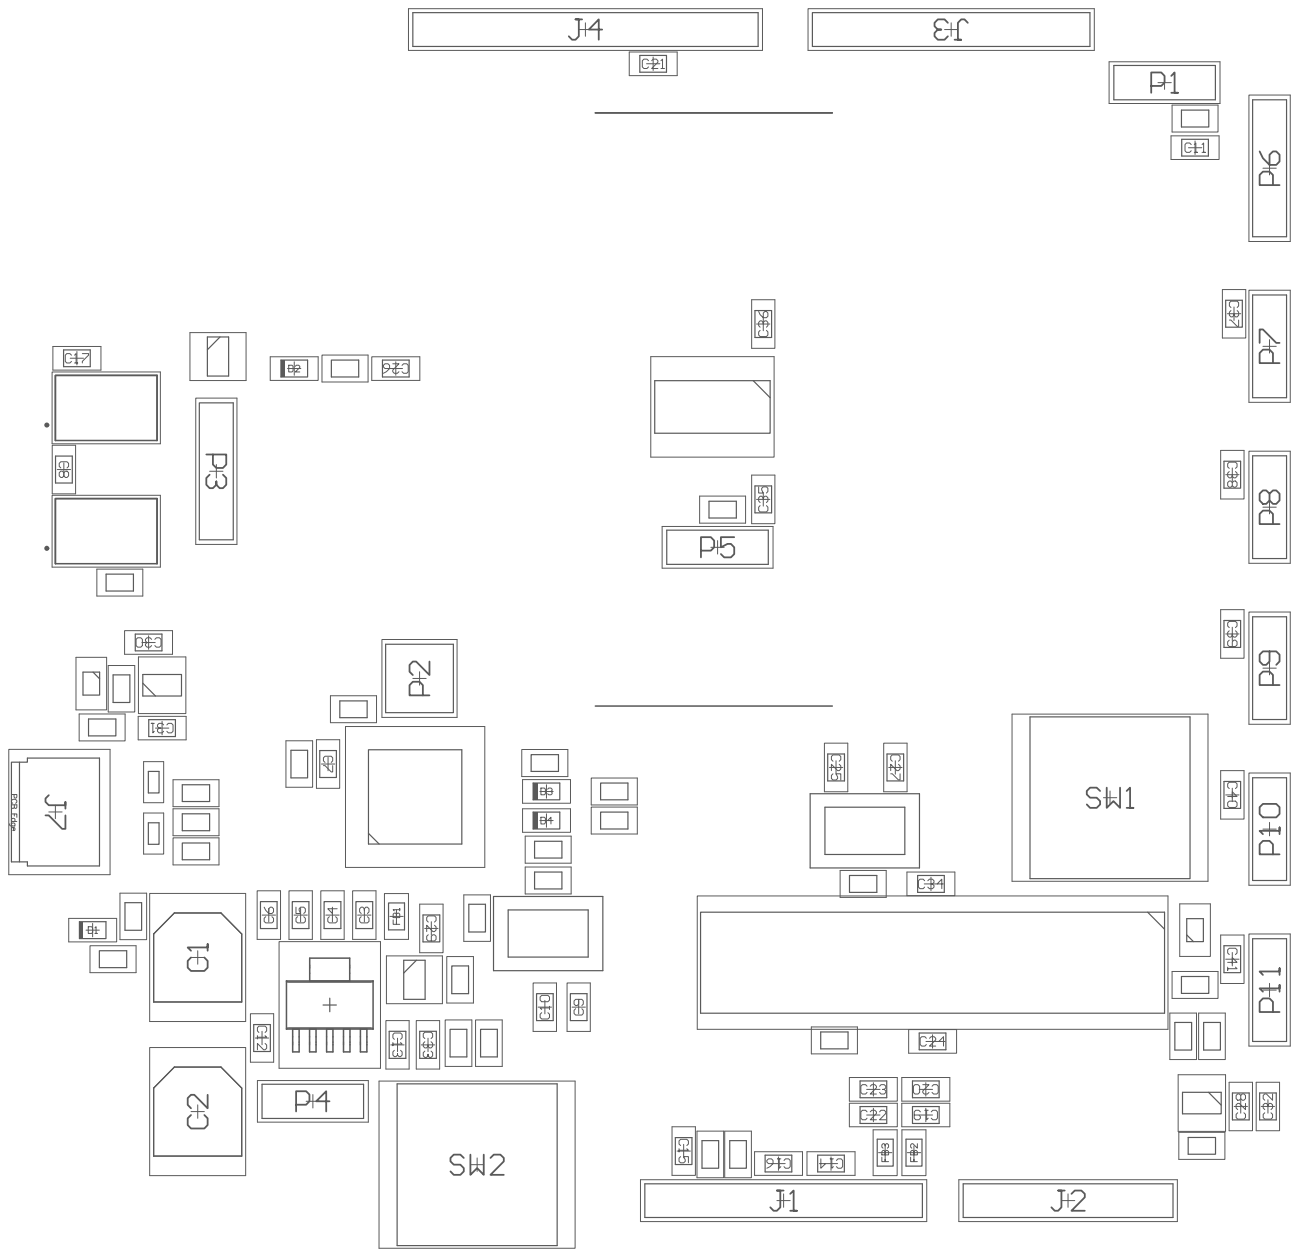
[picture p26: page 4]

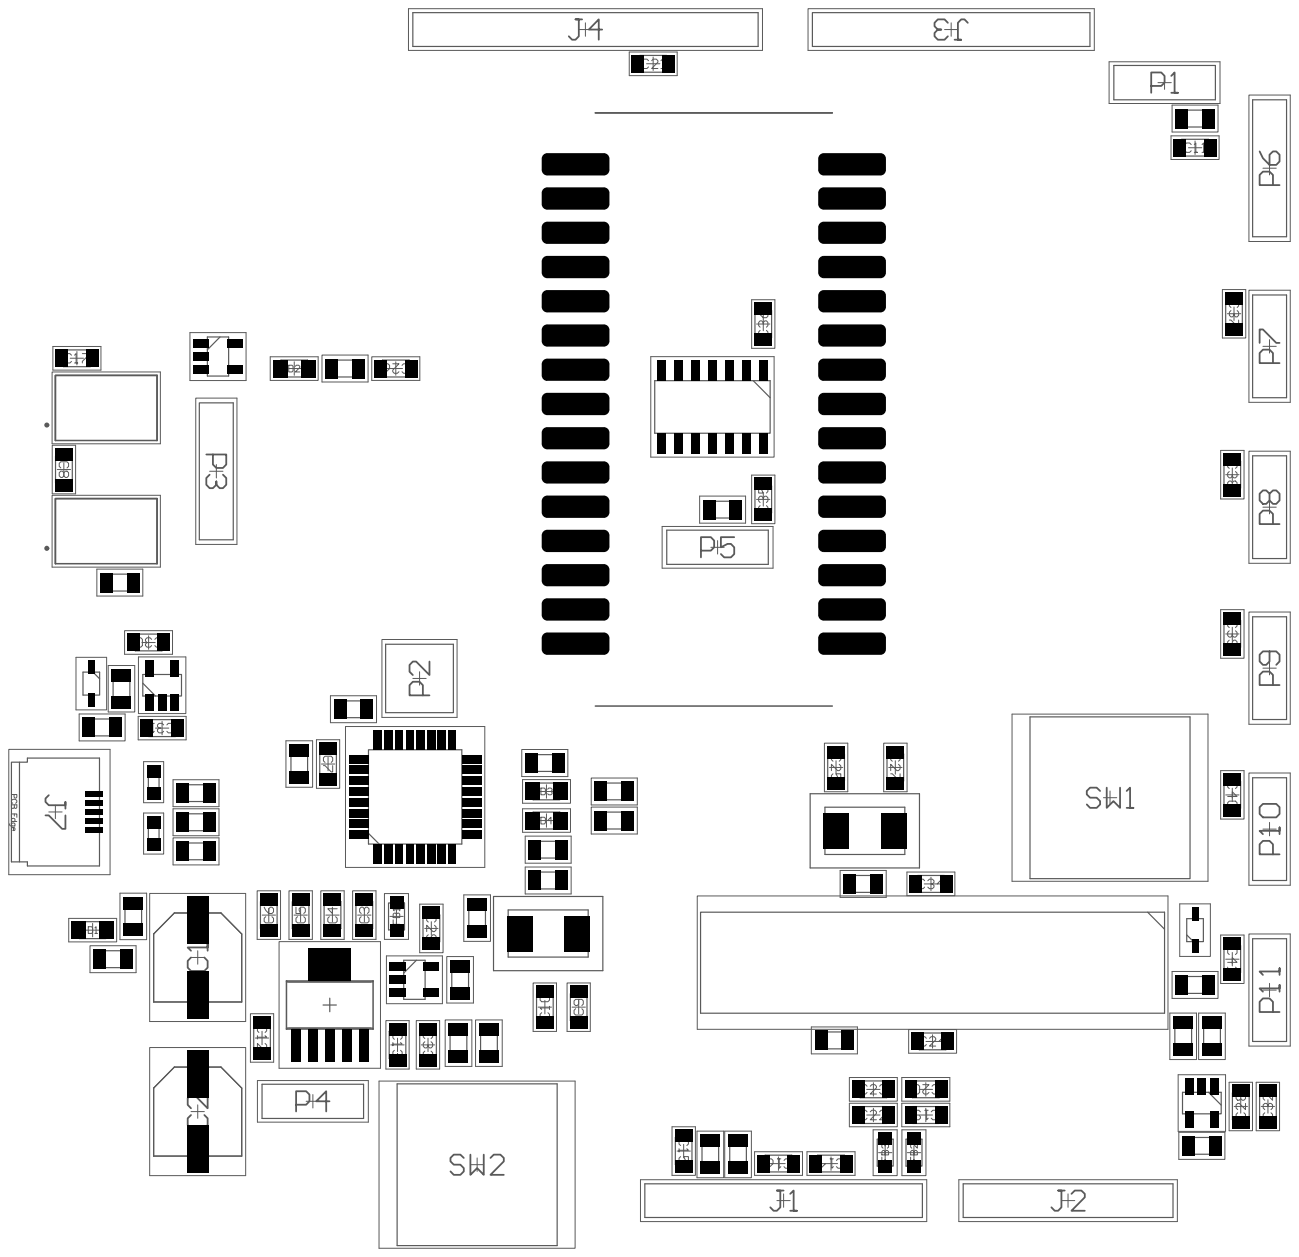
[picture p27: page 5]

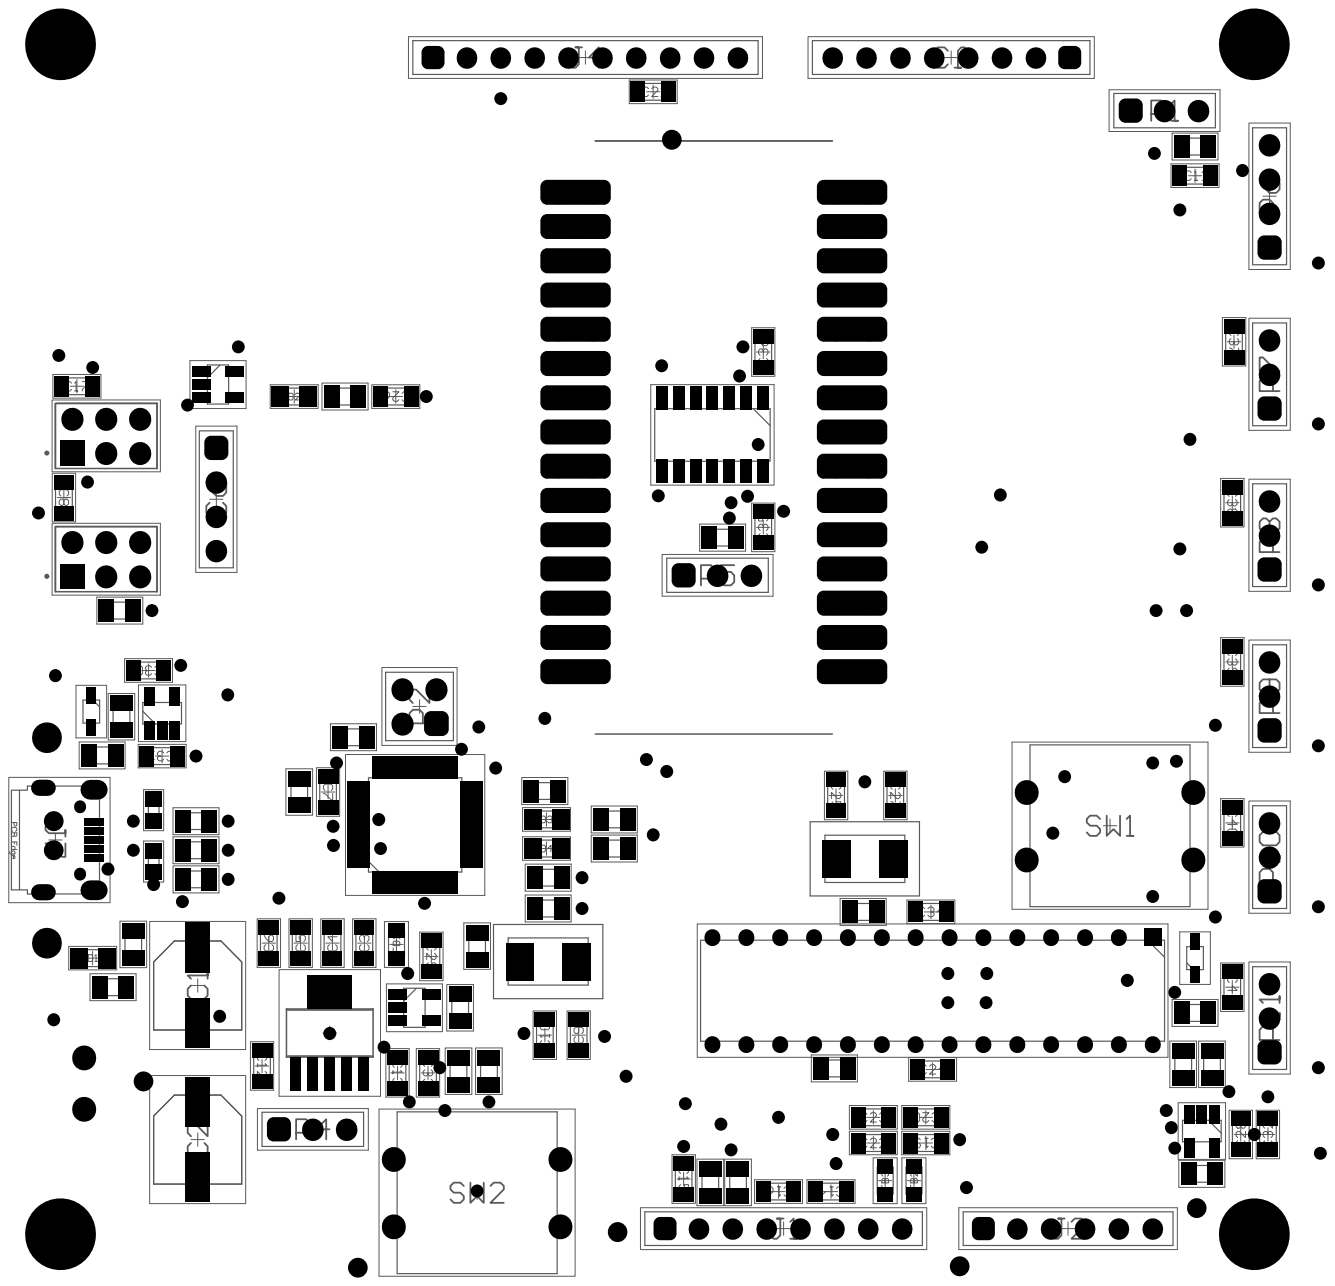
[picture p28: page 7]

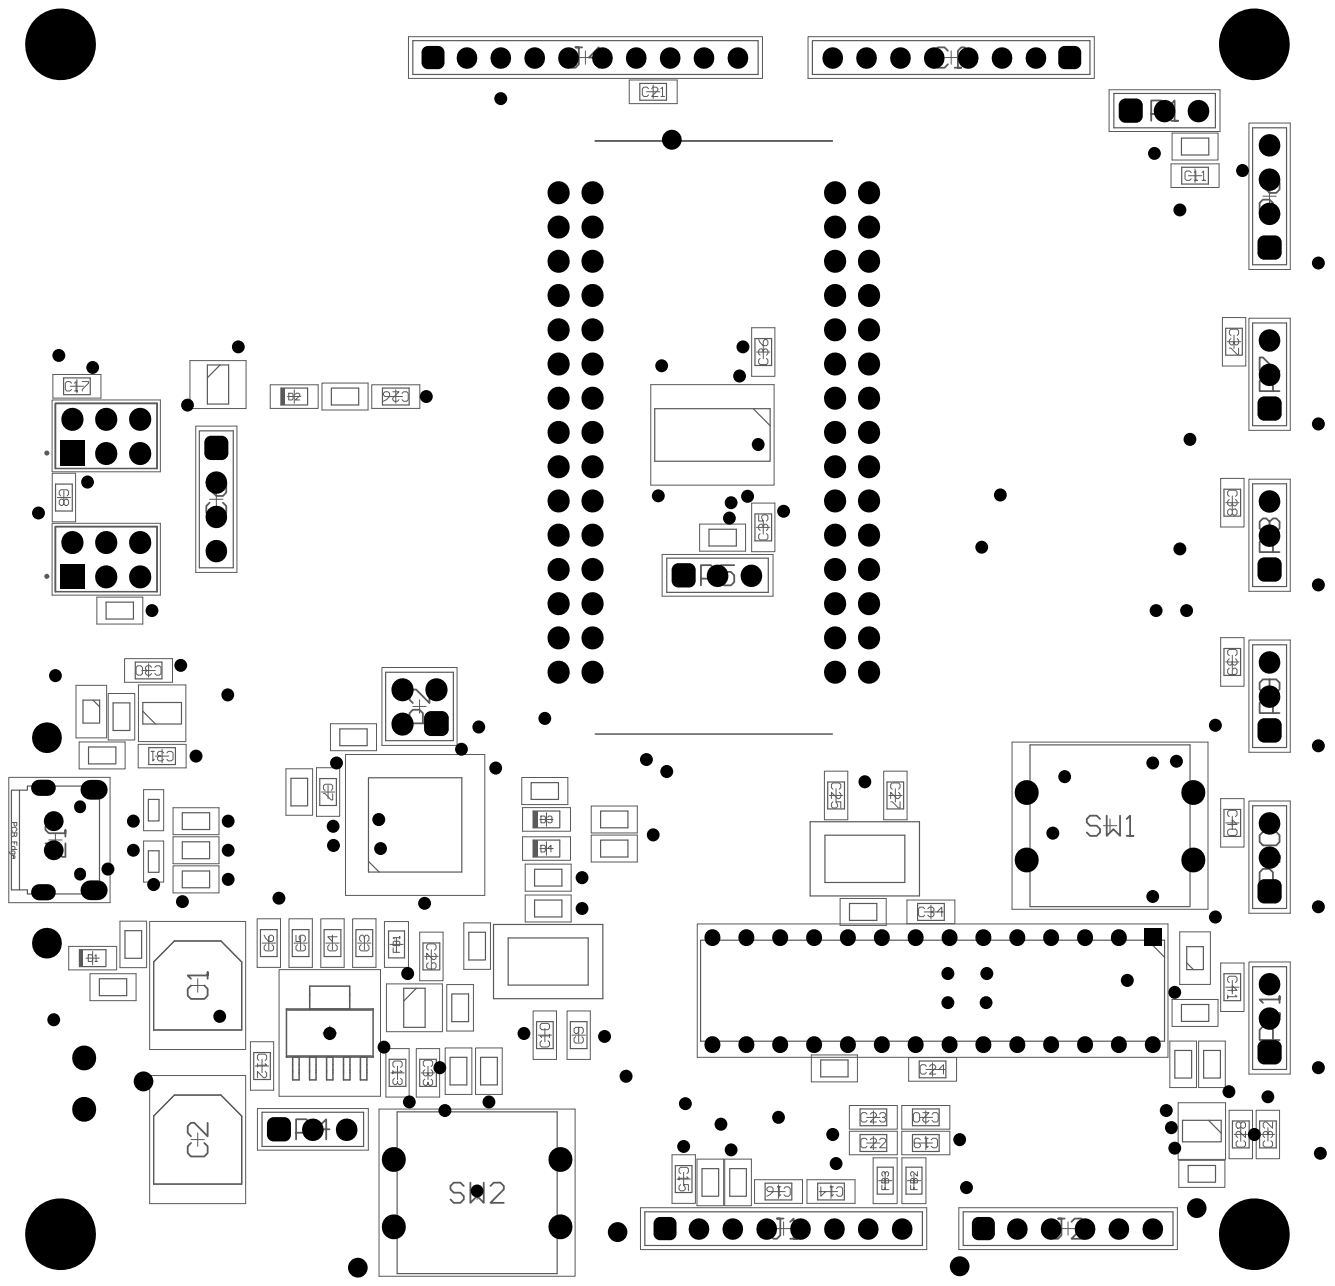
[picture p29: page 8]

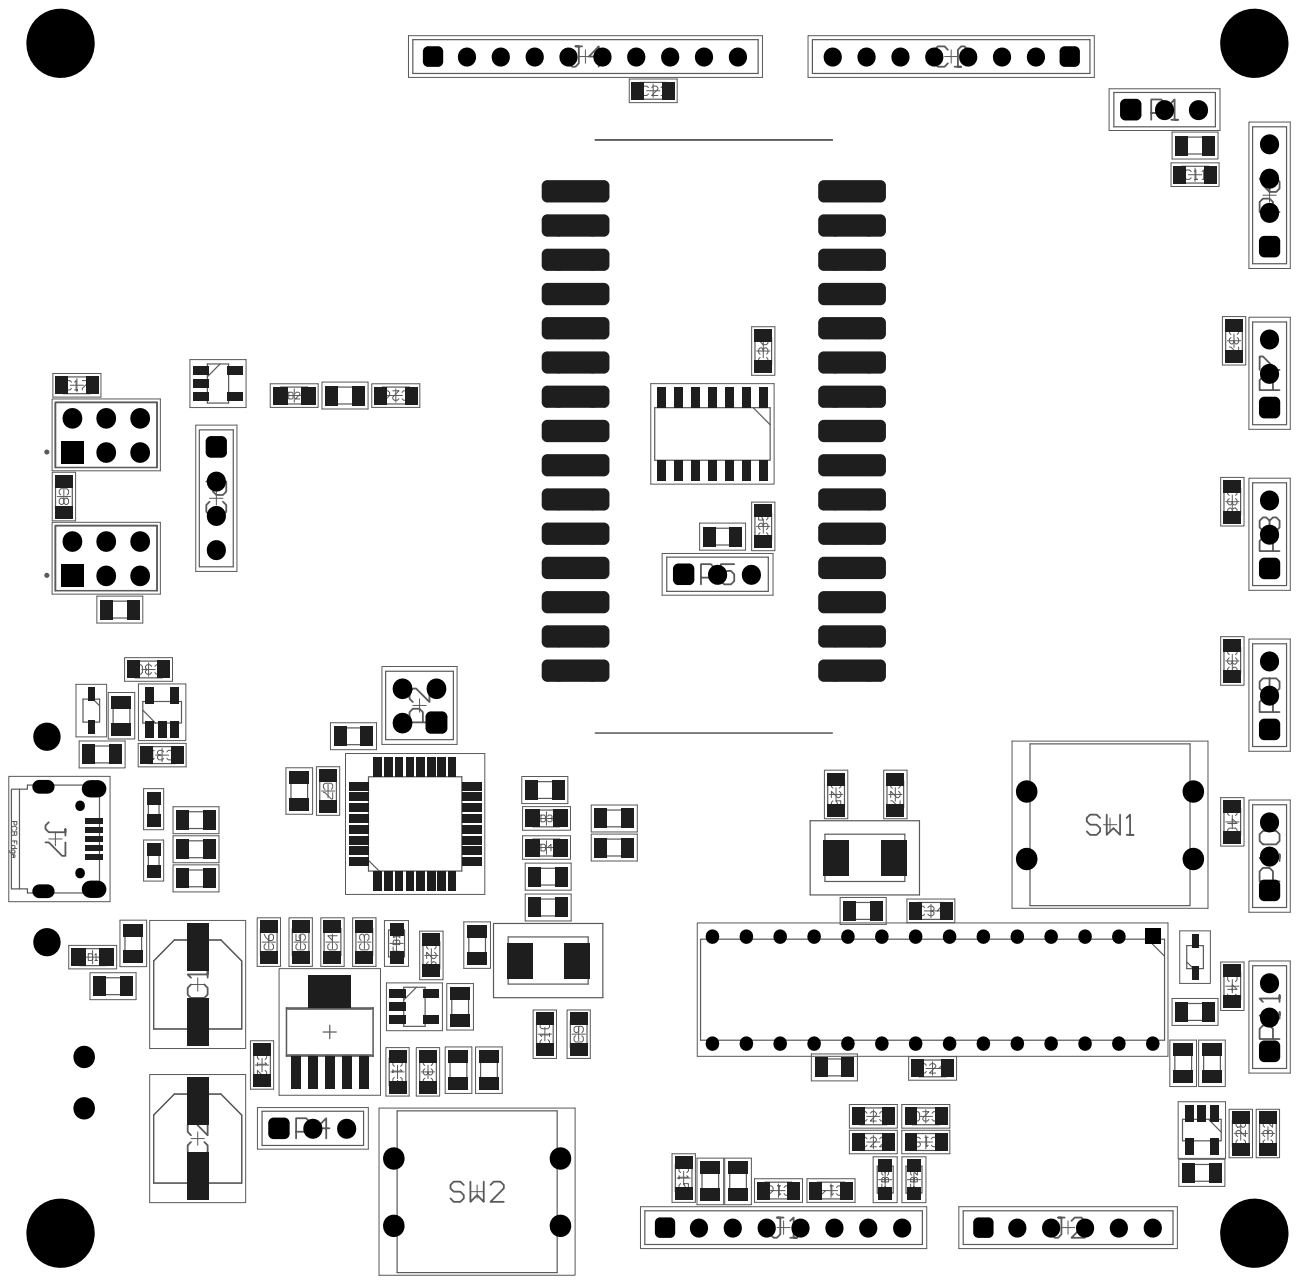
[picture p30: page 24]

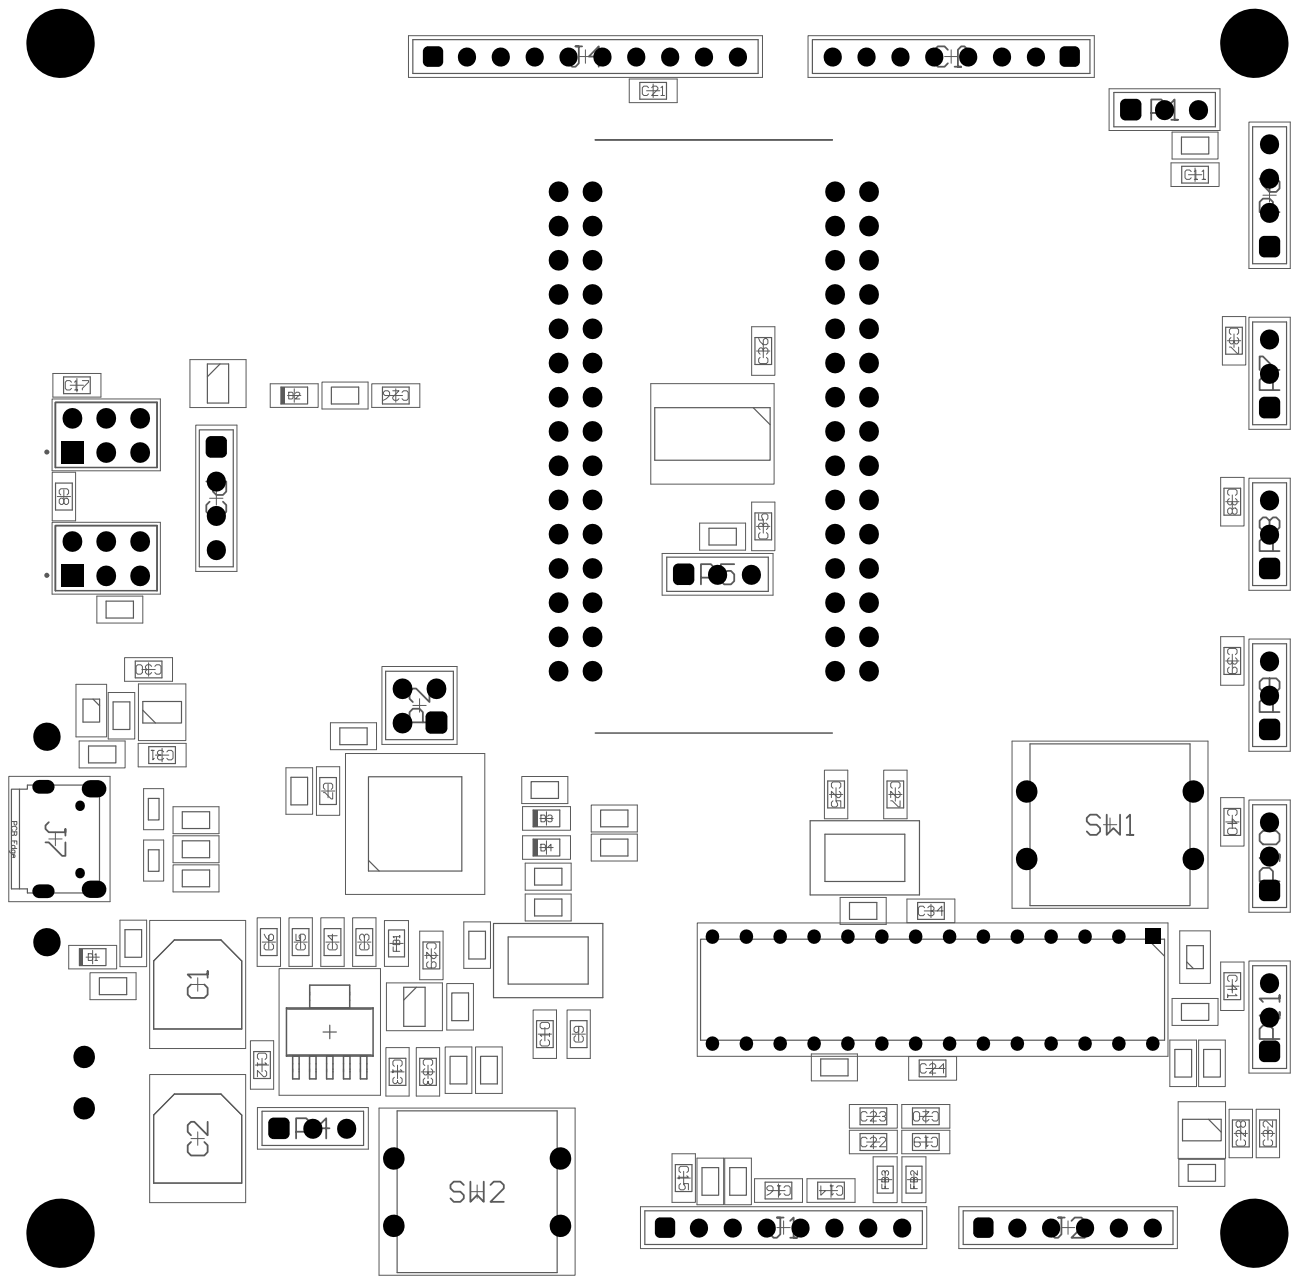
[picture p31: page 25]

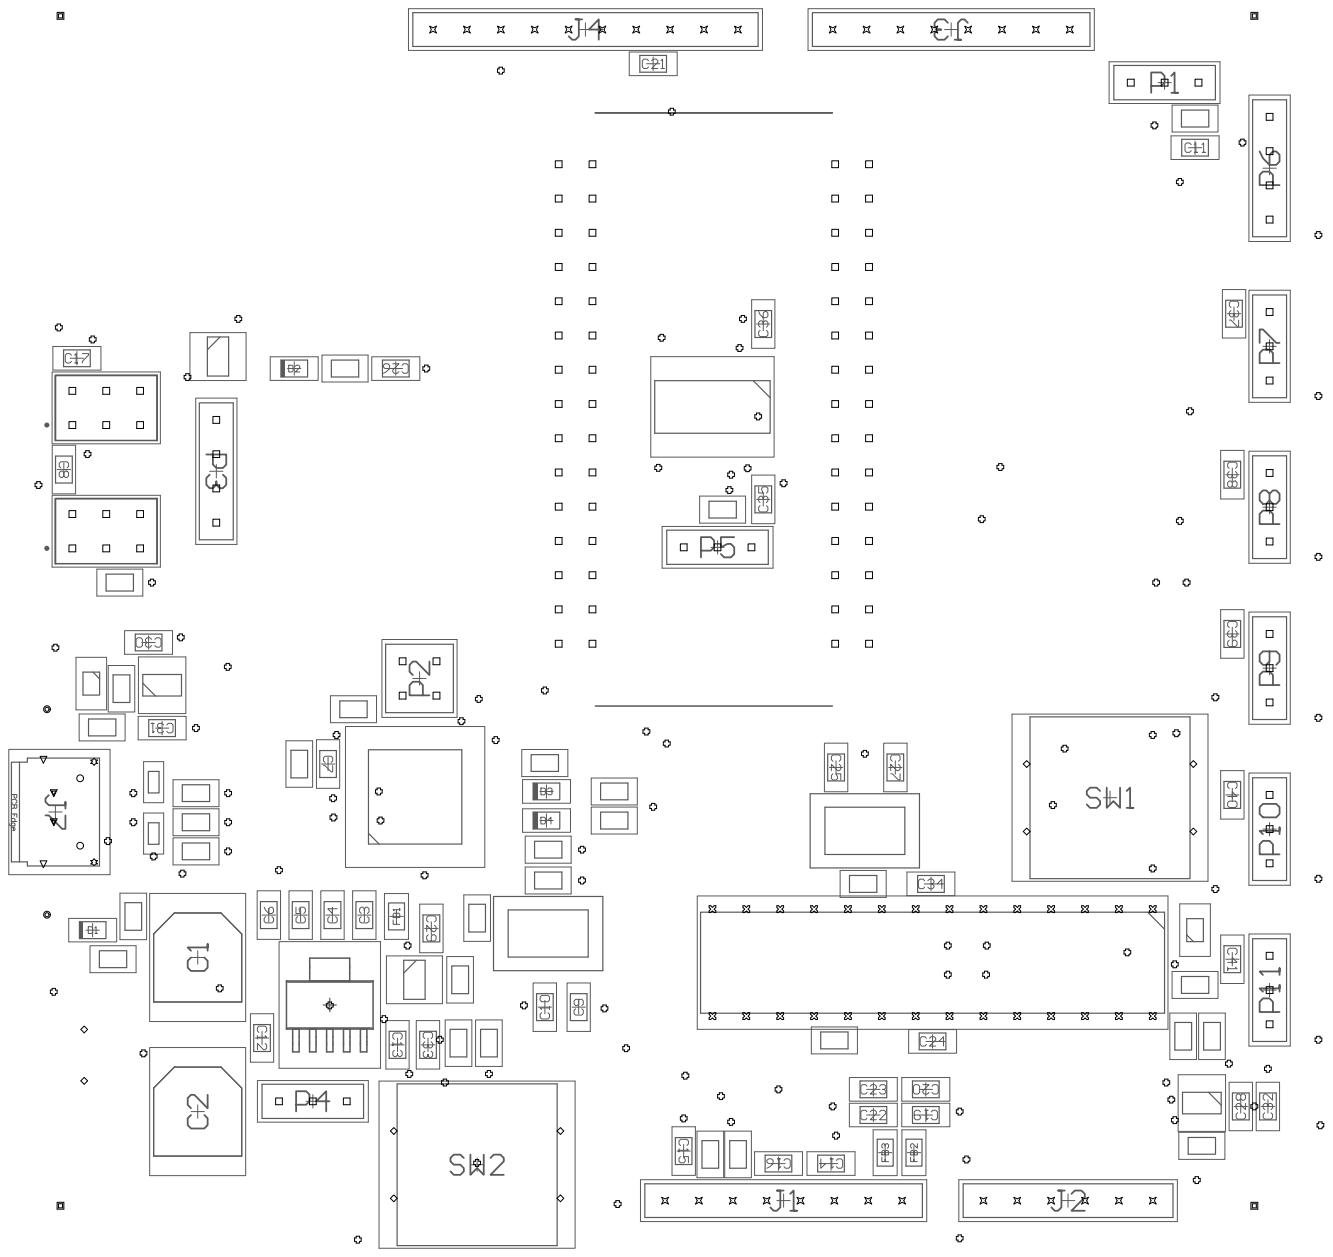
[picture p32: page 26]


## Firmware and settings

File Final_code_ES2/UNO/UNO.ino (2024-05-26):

#include <stdlib.h>
#include <LiquidCrystal_I2C.h> // Library for LCD
#include <SDISerial.h>

#define DATALINE_PIN 2
#define INVERTED 1
#define BUTTON_PIN 8

String VWC;   //volumetric water content
String EC;    // electrical conductivity
String TEMP;  // temperature
char X='+';
char *FTEvalue=new char[20];
int buttonState = 0;
float VWCvalue = 0;
int lastState = HIGH; // the previous state from the input pin
int currentState;    // the current reading from the input pin


String Message = "";
String temperature = "0";
String humidity = "0";
String pressure = "0";
String imu_x = "0", imu_y = "0", imu_z = "0";  // IMU
String color_r = "0", color_g = "0", color_b = "0";  // Color sensor
bool parseFlag = false;
int screenState = 0;

LiquidCrystal_I2C lcd(0x20, 16, 2); // I2C address 0x27, 16 column and 2 rows

SDISerial sdi_serial_connection(DATALINE_PIN, INVERTED);

char* get_measurement(){
	char* service_request = sdi_serial_connection.sdi_query("?M!",150);
	//you can use the time returned above to wait for the service_request_complete
	char* service_request_complete = sdi_serial_connection.wait_for_response(150);
	//dont worry about waiting too long it will return once it gets a response
	return sdi_serial_connection.sdi_query("?D0!",150);
}

void setup() {
  sdi_serial_connection.begin(); // start our SDI connection 
  Serial.begin(9600); // Initialize the Serial communication at 9600 baud rate
  pinMode(BUTTON_PIN, INPUT);

  lcd.init(); //initialize the lcd
  lcd.backlight(); //open the backlight 
  lcd.clear();
  lcd.setCursor(0,0);
  lcd.print("starting...");
  delay(3000);
}

void loop() {
  currentState = digitalRead(BUTTON_PIN);
  if (currentState == HIGH && lastState == LOW) {
    // If the input goes HIGH and the previous state was LOW, change to HIGH
    lastState = HIGH;
  } else if (currentState == LOW && lastState == HIGH) {
    // If the input goes LOW and the previous state was HIGH, change to LOW
    screenState++;

    lastState = LOW;
  }

  if(screenState == 7)
  {
    screenState = 0;
  }

  
    /*
    screenState++;
    if(screenState == 6)
    {
      screenState = 0;
    }
    */


  if (Serial.available()) { // Check if data is available to read
    char receivedChar = Serial.read(); // Read the incoming byte
    Message += receivedChar;
    // Check for the end of a message
    if (receivedChar == '*') {
      parseFlag = true;
    }
  }

  if (parseFlag == true) {
    
 
    char* response = get_measurement(); // get measurement data
    //lcd.clear();
    //lcd.print("measured 1");
    String FTE = response;
    
    int tmp1 = '+';
    int tmp2 = FTE.indexOf(tmp1);
    
    while (tmp2 == -1) {
      char* response = get_measurement(); // get measurement data
      //lcd.clear();
      //lcd.print("measured 2");
      FTE = response;
      tmp2 = FTE.indexOf(tmp1);
    }

    FTE.replace('+', ' '); // Replace '+' signs with spaces

    int FTElength = FTE.length();

    if (FTEvalue[5] == '+') {
      VWC = FTE.substring(2, 5);
      EC = FTE.substring(6, 10);
      TEMP = FTE.substring(11, 15);
    } else {
      VWC = FTE.substring(2, 6);
      EC = FTE.substring(7, 11);
      TEMP = FTE.substring(12, 17);
    }
    VWCvalue = VWC.toInt() / 100.0;
    //lcd.clear();
    //lcd.print("got vwc");

    // Split the message by '*'
    int delimiterIndex = Message.indexOf('*');
    if (delimiterIndex != -1) {
      String data = Message.substring(0, delimiterIndex);
      // Reset message buffer for next iteration
      Message = Message.substring(delimiterIndex + 1);
      // Process the data
      int tempIndex = data.indexOf("temp>");
      int humIndex = data.indexOf("hum>");
      int presIndex = data.indexOf("pres>");
      int imuIndex = data.indexOf("imu>");
      int colIndex = data.indexOf("col>");
      if (tempIndex != -1) {
        temperature = data.substring(tempIndex + 5, humIndex - 1);
      }
      if (humIndex != -1) {
        humidity = data.substring(humIndex + 4, presIndex - 1);
      }
      if (presIndex != -1) {
        pressure = data.substring(presIndex + 5, imuIndex - 1);
      }
      if (imuIndex != -1) {
        int comma1 = data.indexOf(',', imuIndex);
        int comma2 = data.indexOf(',', comma1 + 1);
        imu_x = data.substring(imuIndex + 4, comma1);
        imu_y = data.substring(comma1 + 2, comma2);
        imu_z = data.substring(comma2 + 2, colIndex - 1);
      }
      if (colIndex != -1) {
        int comma1 = data.indexOf(',', colIndex);
        int comma2 = data.indexOf(',', comma1 + 1);
        color_r = data.substring(colIndex + 4, comma1);
        color_g = data.substring(comma1 + 2, comma2);
        color_b = data.substring(comma2 + 2);
      }
      /*
      // Print the parsed values
      Serial.print("Temperature: ");
      Serial.println(temperature);
      Serial.print("Humidity: ");
      Serial.println(humidity);
      Serial.print("Pressure: ");
      Serial.println(pressure);
      Serial.print("IMU - X: ");
      Serial.println(imu_x);
      Serial.print("IMU - Y: ");
      Serial.println(imu_y);
      Serial.print("IMU - Z: ");
      Serial.println(imu_z);
      Serial.print("Color - R: ");
      Serial.println(color_r);
      Serial.print("Color - G: ");
      Serial.println(color_g);
      Serial.print("Color - B: ");
      Serial.println(color_b);


      */


    }
    switch(screenState)
    {
      case 0:
        lcd.clear();
        lcd.setCursor(0, 0);
        lcd.print("Temperature:");
        lcd.setCursor(0, 1);
        lcd.print(temperature);
      break;
      case 1:
        lcd.clear();
        lcd.setCursor(0, 0);
        lcd.print("Humidity:");
        lcd.setCursor(0, 1);
        lcd.print(humidity);
      break;
      case 2:
        lcd.clear();
        lcd.setCursor(0, 0);
        lcd.print("Pressure:");
        lcd.setCursor(0, 1);
        lcd.print(pressure);
      break;
      case 3:
        lcd.clear();
        lcd.setCursor(0, 0);
        lcd.print("IMU: x ");
        lcd.print(imu_x);

        lcd.setCursor(0, 1);
        lcd.print(" y ");
        lcd.print(imu_y);
        lcd.print(" z ");
        lcd.print(imu_z);

      break;
      case 4:
        lcd.clear();
        lcd.setCursor(0, 0);
        lcd.print("Color: r ");
        lcd.print(color_r);

        lcd.setCursor(0, 1);
        lcd.print(" g ");
        lcd.print(color_g);
        lcd.print(" b ");
        lcd.print(color_b);

      break;
      case 5:
        lcd.clear();                 // clear display
        lcd.setCursor(0, 0);         // move cursor to   (0, 0)
        lcd.print("VWC1 = ");        // print message at (0, 0)
        lcd.setCursor(7, 0);
        lcd.print(VWCvalue);
        lcd.setCursor(0, 1);
        lcd.print("EC = ");
        lcd.setCursor(5, 1);
        lcd.print(EC);
        lcd.setCursor(12, 0);
        lcd.print("Temp");
        lcd.setCursor(12, 1);
        lcd.print(TEMP);
      break;
      
      default:
        return 0;
      break;
    }
    
      delay(500);
      parseFlag = false; // Reset parseFlag
  }
}

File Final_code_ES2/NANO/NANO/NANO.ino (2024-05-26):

/* This is a test skecth that can be used for internal testing of Nano 33 BLE sense sensors */
#include <stdlib.h>
#include <Arduino_HTS221.h>   //  Tempeature and Humidity sensor

#include <Arduino_LPS22HB.h>  // Pressure sensor

#include <Arduino_LSM9DS1.h>  // IMU 

#include <Arduino_APDS9960.h>   // Color sensor

String Message = "";
void setup() {
  Serial.begin(9600);
  Serial1.begin(9600);

  // Initiate the HTS2221 Sensor
  if (!HTS.begin()) {
    Serial.println("Failed to initialize humidity temperature sensor!");
    while (1);
  }

  // Initiate the pressure sensor
  if (!BARO.begin()) {
    Serial.println("Failed to initialize pressure sensor!");
    while (1);
  }
  // initiate IMU
  if (!IMU.begin()) {  
    Serial.println("IMU init failed");  
    while (1) {}  
  } 
  // Initiate Color sensor
  if(!APDS.begin()){
    Serial.println("Failed to initialize colour sensor!");
  }

}

void loop() {
  // read all the sensor values
  float temperature = HTS.readTemperature();
  float humidity    = HTS.readHumidity();
  float pressure = BARO.readPressure();
  float x, y, z;  // IMU
  int r, g, b;  // Color sensor

  // Color sensor Test
  if (APDS.colorAvailable()) {

    // Read Color
    APDS.readColor(r, g, b);

    // print the values
    Serial.print("r = ");
    Serial.println(r);
    Serial.print("g = ");
    Serial.println(g);
    Serial.print("b = ");
    Serial.println(b);
    Serial.println();
  }
  
  // IMU test
  if (IMU.accelerationAvailable()) {

    // Read Accelerometer
    IMU.readAcceleration(x, y, z);

    Serial.print("x");
    Serial.print('\t');
    Serial.print("y");
    Serial.print('\t');
    Serial.print("z");
    Serial.print('\n');
    Serial.print(x);
    Serial.print('\t');
    Serial.print(y);
    Serial.print('\t');
    Serial.println(z);
  }

  // Temperature and Humidity sensor test
  Serial.print("Temperature = ");
  Serial.print(temperature);
  Serial.println(" °C");

  Serial.print("Humidity    = ");
  Serial.print(humidity);
  Serial.println(" %");

  // Pressure sensor test
  Serial.print("Pressure = ");
  Serial.print(pressure);
  Serial.println(" kPa");

  // print an empty line
  Serial.println();

  Message = "temp>";
  Message += temperature;

  Message += ">hum>";
  Message += humidity;

  Message += ">pres>";
  Message += pressure;

  Message += ">imu>";
  Message += x;
  Message += ", ";
  Message += y;
  Message += ", ";
  Message += z;

  Message += ">col>";
  Message += r;
  Message += ", ";
  Message += g;
  Message += ", ";
  Message += b;
  Message += ">";
  Message += "*";
  Message += ">";

  Serial1.println(Message);
  Serial.print(Message);




  // wait 1 second to print again
  delay(3000);
}

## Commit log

2024-02-20 Datasheets 5TE moisture sensor
2024-02-20 Datasheet Arduino 33 Sense PINOUT
2024-02-20 Datasheet Arduino 33 Sense (FULL)
2024-02-20 Datasheet Arduino 33 sense SCHEMATICS
2024-02-20 Datasheet 5TE soil moisture sensor
2024-04-16 PCB Design
    [GH_PcbLib.PcbLib, GH_SchematicLib.SchLib, Greenhouse.PcbDoc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]
